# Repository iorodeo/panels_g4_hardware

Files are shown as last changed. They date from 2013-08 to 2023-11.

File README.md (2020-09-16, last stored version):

---
title: other Hardware
parent: Setup
grand_parent: Generation 4
nav_order: 4
---

# G4 Hardware

The original development of the G4 Hardware Panels. Currently, in the year 2020, the communication board and the programmer are still being used. The driver has been replaced with a specialized board. Also, there are different arena boards used.

The current version of the communication board (`comm`) and `programmer` are in `atmega328/four_panel/20mm_matrix/ver3`.

In addition, the directory `placeholder` contains a panel, which can be used as a drop in replacement for a panel with a 35mm×21mm opening to look through.

## Project structure

```
├── atmega328
│   ├── four_panel
│   └── one_panel
├── max6960
│   ├── four_panel
│   ├── one_panel
│   └── two_panel
├── stm32
│   ├── pcb_big_v0
│   └── pcb_big_v1
└── placeholder
```

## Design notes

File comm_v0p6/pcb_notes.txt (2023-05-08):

1. Fixed issue with schematic design rules check. Changed Schematic Setup ->
Electrical Rules -> Violation Severity -> Miscellaneous -> SPICE model issue to
ignore.

2. Problem with vias. Via hole (0.5mm) is larger than via diameter (0.3mm).
JLCPCB may have corrected this for you automatically. However, you could run
into an issue with other board houses. They will probably catch it, but it
might hang up the order.  JLCPCB specs say via diameter should be 0.1mm(0.15mm
preferred) larger than Via hole size.

3. Also, vias might be to small in general.  

4. Moved to 4-layer [sig+pwr, gnd, gnd, sig+pwr] stackup.

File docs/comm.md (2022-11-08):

---
title: Comm Board
parent: Acquisition
grand_parent: Generation 4
nav_order: 5
---

1. TOC
{:toc}

# Communication PCB

The communication PCB or "comm board" measures 40×40mm² and has a 15 pin connector on the bottom and a matching socket on the top edge. In addition, there are four 4×4 female sockets ([v0.3](#comm-v0p3)) or two 3×6 male pins ([v0.1](#comm-v0p1)) on the top side of the PCB. This board extracts data packets for the current panel from the SPI stream and sends them via I²C to the driver board. The connectors always need to be connected to either a adjacent comm board or an arena.

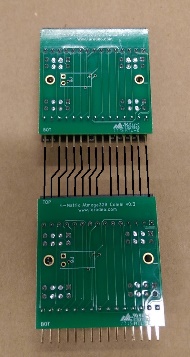
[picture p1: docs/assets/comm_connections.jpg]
Connections between panels


To identify packets for the current panel, each comm uses four of its connectors as "chip select" lines. This means, while the first chip select line is active, the comm board splits and forwards the received data to the driver board. Independently, the data is always forwarded to the next panel. In addition, the comm board drops the first chip select line from the input and makes the second input chip select line the first output chip select, the 3rd becomes second, and the fourth the 3rd output. This way, up to four stacked panel PCB can be addressed individually.

While the chip select line is active for the current panel, a micro controller unit (MCU) splits the incoming signal into smaller chunks. The driver boards are usually divided into quadrants, and the comm board forwards the matching data packages to the quadrants via I²C bus. The change of protocol has historic reasons. Most recent [comm boards v0.3](#comm-v0p3) use four connectors for the driver board, earlier versions had only two.

## Panel Comm PCB v0.3 {#comm-v0p3}

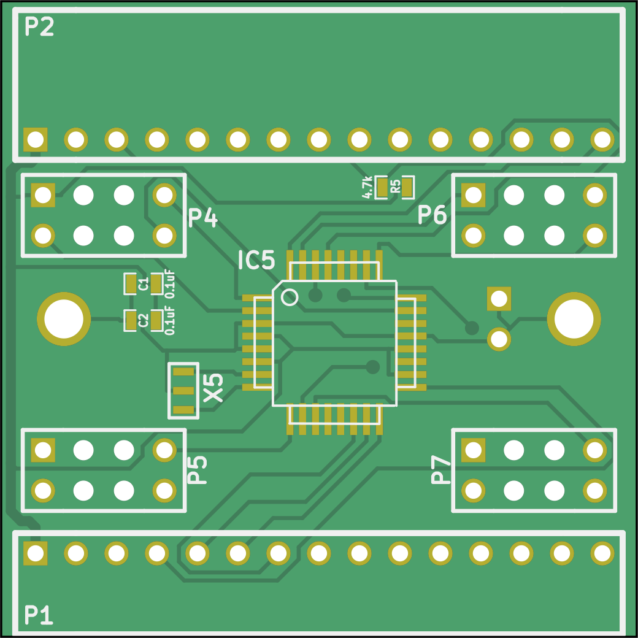
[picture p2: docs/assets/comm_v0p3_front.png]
A rendering of the communication board v0.3 front


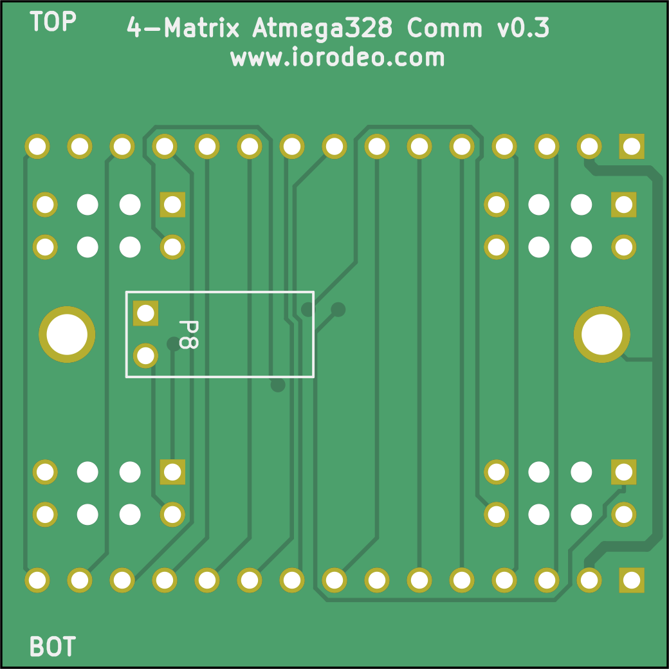
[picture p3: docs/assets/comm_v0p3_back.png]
A rendering of the communication board v0.3 back


The communication board is a 40×40mm² PCB with two layers, most recently available as version v0.3 available in `comm_v0p3` (see [schematic](assets/comm_v0p3_schematic.pdf)). The connectors are designed as through-hole, other components are SMD.

### Function

The comm board v0.3 receive signals (P1), send them on (P2). Based on the chip select line it identifies the signals relevant for the current panel. This processing is done with the help of a 20MHz ATmega328P-AUR (IC5). The relevant signals are passed to one of the four driver board quadrants (P4…P7).

### Design

The files are inside the `comm_v0p3` folder and find the production files inside the `comm_v0p3/production_v0/` directory.

The design files are shared under a creative commons license as [KiCad](https://kicad-pcb.org/) EDA source files. They were initially developed by [IORodeo](https://iorodeo.com). If you open the schematics in a current version of KiCad you might be asked to remap the symbols when you first open the files.

### Production

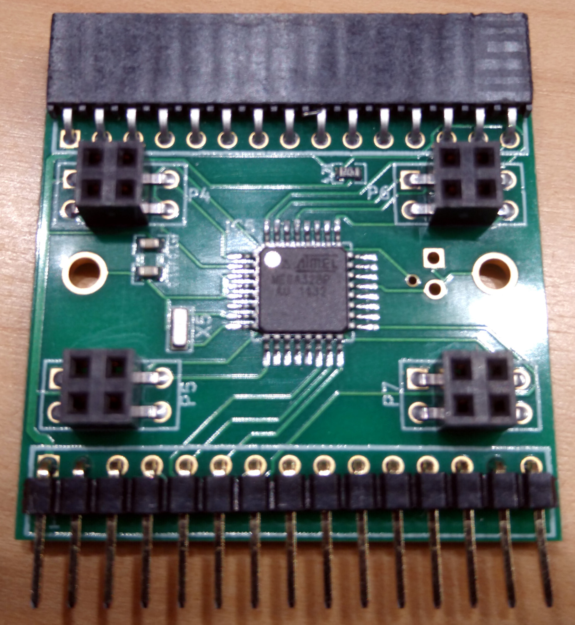
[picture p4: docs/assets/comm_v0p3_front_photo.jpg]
A picture of the assembled board v0.3


The Comm board v0.3 is a two layer PCB with 1oz copper that has no special requirements on the production process. We typically order them on the default FR-4. The board has through-hole components such as the connectors, but the majority of components are SMD with the smallest package of 0603 (imperial) or 1608 (metric).

For an order volume of 150 pieces we would expect prices around $16 for the assembled board. This might be around $1.50 for the board, $8 for the components, $6 for the assembly, and $.50 for shipping. Recently we have had good experiences with [Bittele](https://www.7pcb.com/). If you decide to order at Bittele, you can provide quotation Q70762A1 and order number 39493C2 as references for successful builds.

## Panel Window PCB {#window}

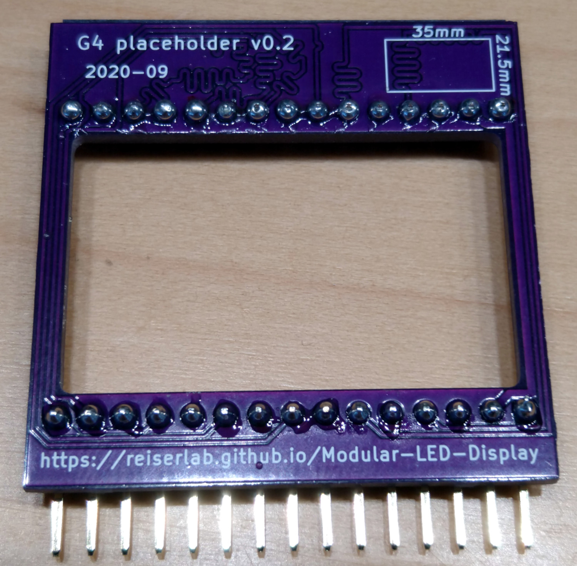
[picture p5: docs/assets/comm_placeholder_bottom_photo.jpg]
The assembled window PCB (as "placeholder v0.2")


This PCB acts as a drop-in replacement for panels within a column. It has a cut out of 35×21mm² which you can use to point a camera or other device through that column. In most cases this is not needed, yet it is the most simple and cheap PCB you can get produced from the G4 system. So if you haven't had any experience with the process of ordering PCBs, you might want to start here. Before version v0.3 this was called "placeholder".

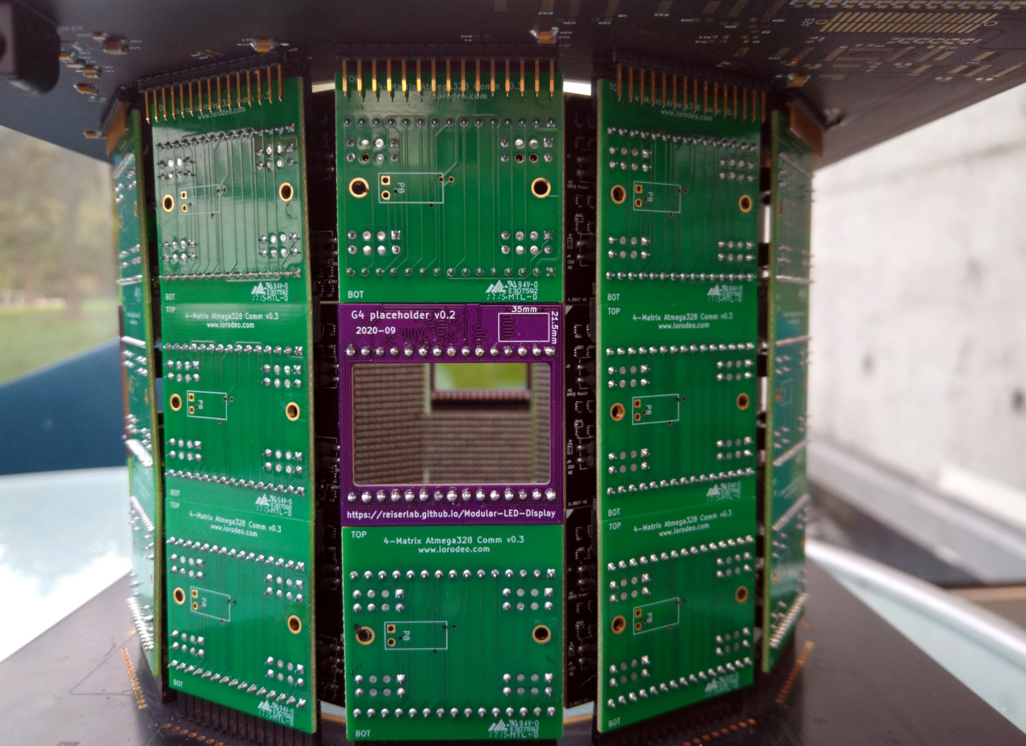
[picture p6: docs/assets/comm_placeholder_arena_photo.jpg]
Window PCB placed in a full 12-12 arena v1, allowing to see through


If you want to skip a panel within a column, you will need to connect the chip select lines accordingly. The image on the right shows which input and output connectors your want to connect. Note, that the signal is travelling from the bottom to the top. This has often been done with wires.

Alternatively you can use the window PCB to achieve the same. The PCB has the same outer dimensions and same connectors as the Comm PCB and provides the wiring described above between input and output.

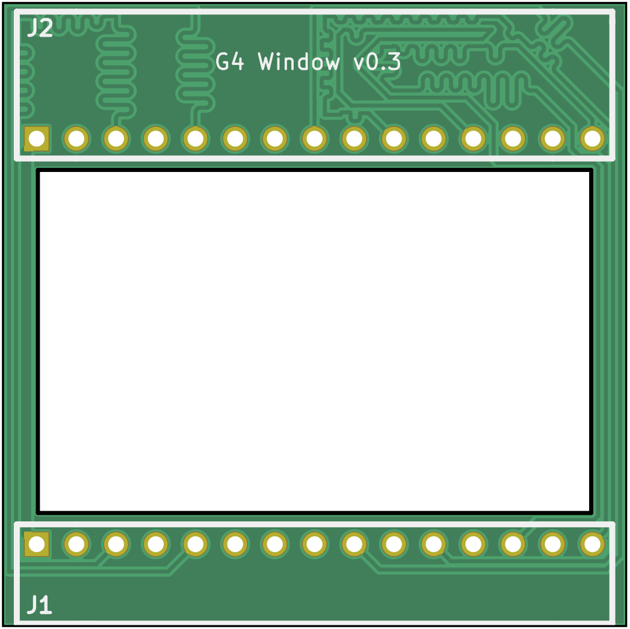
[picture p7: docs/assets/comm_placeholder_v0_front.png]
A rendering of the "window" v0.3 (front)


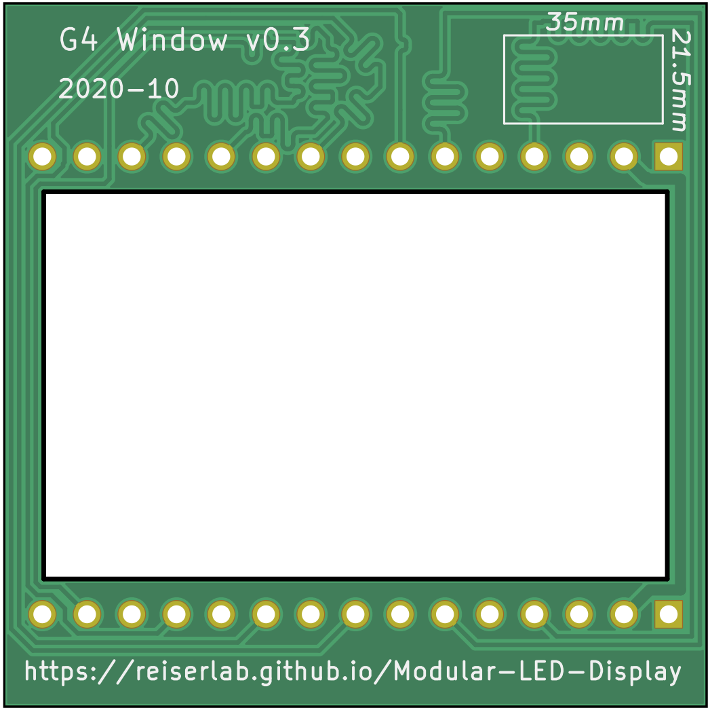
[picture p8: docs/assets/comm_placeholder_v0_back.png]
A rendering of the "window" v0.3


The KiCad design files for this simple 2-layer PCB are in the folder `comm_placeholder_v0`. The files ready for production are inside the `comm_placeholder_v0/production_v0` folder. Most recently `comm_placeholder_v0p3.zip` uses length matched traces. All you need to order this design is the zip file, which contains the relevant files from the directory, and most manufacturers will accept. So far we have ordered this exact design from [OSHPark](https://oshpark.com/) with a quick turn-around time of around 5 days and a total cost of $10 per board, including components. With enough lead time, higher quantities, and other manufacturers the price should be around $1 per unit. For example, in October 2020 an order of 30 window PCB at [JLCPCB](https://jlcpcb.com/) cost less than $20 including shipping and was delivered within 14 days.

The window might be a good start to familiarize yourself with file types, the organization of our repositories, and the whole production process, if you have never done that before. Otherwise please apologize the boring details in the text above.

# Connections

The bottom pins have the following meanings, seen from the direction of the driver:

| No | Name | Description  |
| --:|:---|:---|
|  1 | `5VCC` | (5V Power) |
|  2 | `GND` | (Ground) |
|  3 | `RESET_MAIN` | (Reset all panels) |
|  4 | `SCK` | (Serial Clock) |
|  5 | `COPI` | (Controller Out, Peripheral In) |
|  6 | `CIPO` | (Controller In, Peripheral Out) |
|  7 | `CS1` | (Chip Select 1) |
|  8 | `CS2` | (Chip Select 2) |
|  9 | `CS3` | (Chip Select 3) |
| 10 | `CS4` | (Chip Select 4) |
| 11 | `CS5` | (Chip Select 5) |
| 12 | `CS6` | (Chip Select 6) |
| 13 | `CS7` | (Chip Select 7) |
| 14 | `NC` | (Not Connected) |
| 15 | `EXT_INTO` |  |

Here, `SCK`, `COPI`, `CIPO`, and `CSx` are used for the SPI communication. `RESET_MAIN` sends a reset signal to all MCUs.

# Historic designs

These designs are kept for historic reasons and to debug existing systems. If you have one of them, you probably know what to do and just need the files. If you are building a new system, don't use them.

## Panel Comm PCB v0.2 {#comm-v0p2}

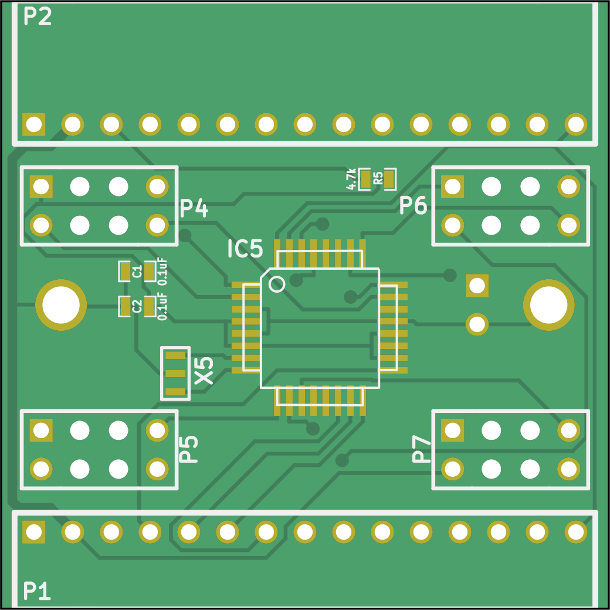
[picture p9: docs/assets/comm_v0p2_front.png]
Rendering of the communication board v0.2 (front)


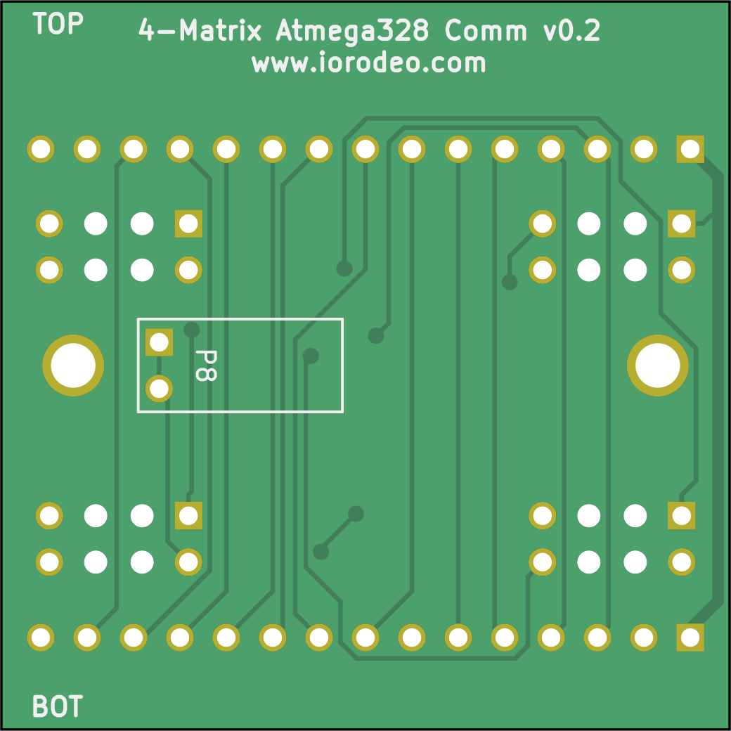
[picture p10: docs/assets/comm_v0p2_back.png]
Rendering of the communication board v0.2 (back)


In theory, the v0.2 should have a 2×3 pin connector that was used for a brief time in certain drivers. The actual comm board with the 2×3 connector seems to be lost, so at this time we are not sure what version 0.2 is. If you wanna try and have a look at the [schematic](assets/comm_v0p2_schematic.pdf), feel free to use the project files in `comm_v0p2`.

Everything else regarding design and production is very similar to the [Comm board v0.3](#comm-v0p3). There is no reason to build a comm board v0.2, except maybe replacing a broken one. Even then you might consider an upgrade of your hardware instead, especially with the unknown background.

The original documentation for v0.2 contained hints that the communication was changed from I²C to SPI and that the board-to-board headers were improved.

## Panel Comm PCB v0.1
{:.clear #comm-v0p1}

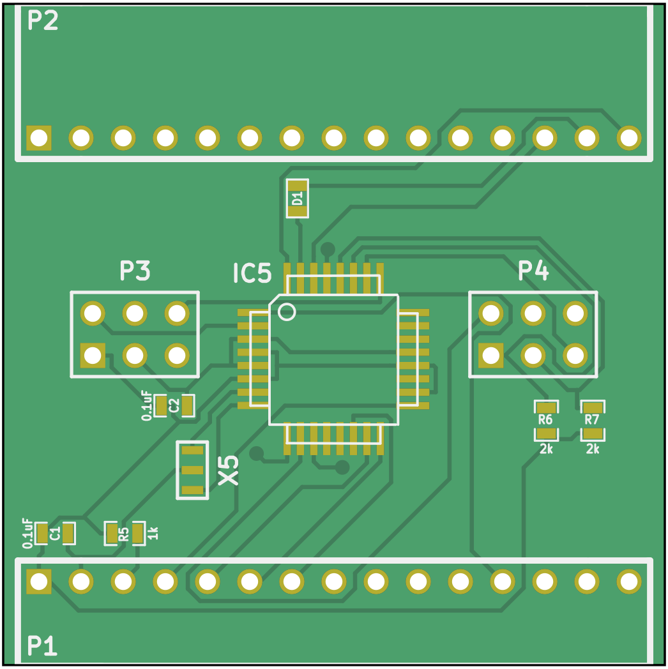
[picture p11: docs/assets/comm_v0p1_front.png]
Rendering of the communication board v0.1 (front)


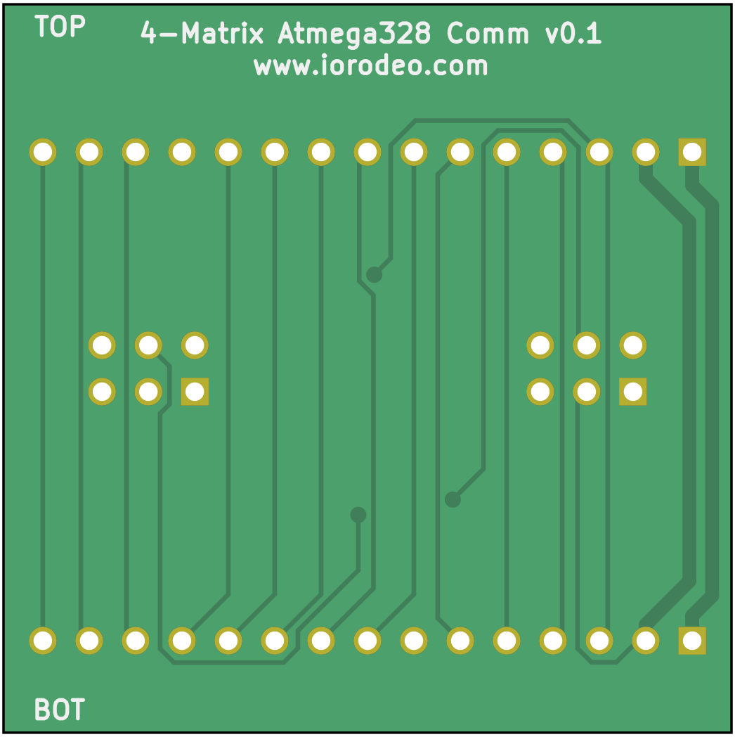
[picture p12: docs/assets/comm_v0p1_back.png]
Rendering of the communication board v0.1


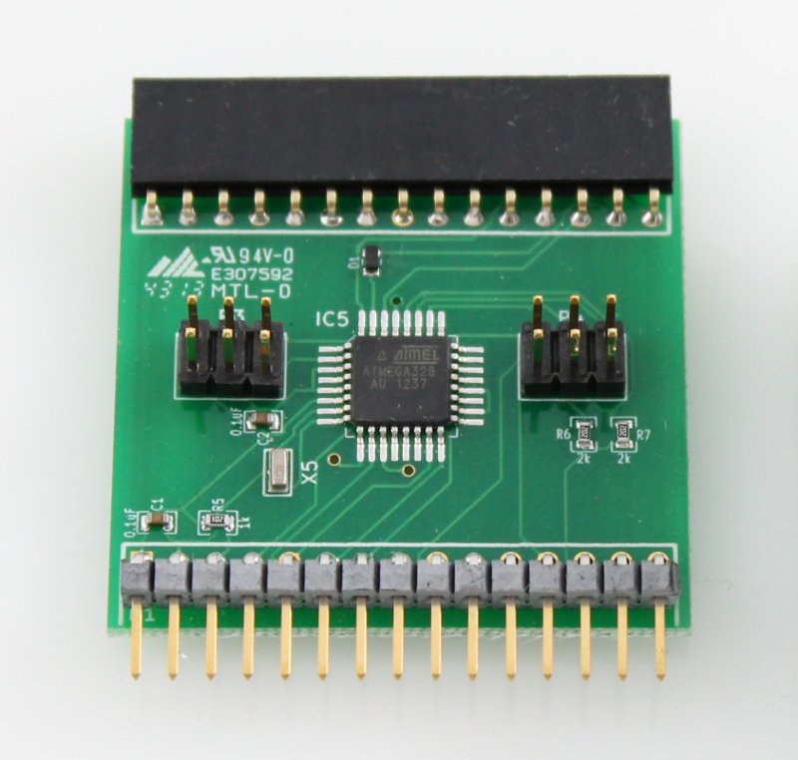
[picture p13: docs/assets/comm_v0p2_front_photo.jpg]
A picture of the assembled comm board v0.1 (front)


`comm_v0p1` contains an earlier comm board project (see [schematic](assets/comm_v0p1_schematic.pdf)). This uses a different communication protocol and is not compatible with drivers-v0.2 and up. The files are there, should you need to repair your existing system with [driver-v0.1]({{site.baseurl}}/Generation%204/Panel/docs/driver.html#driver-v0p1).

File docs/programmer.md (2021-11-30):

---
title: Programmer
parent: Acquisition
grand_parent: Generation 4
nav_order: 8
---

1. TOC
{:toc}

# Programmer

The programmer is built from 3 PCB: An Arduino shield, the comm programmer, and the driver programmer. The three boards are designed to be assembled by hand: These simple 2-layer boards use very few through-hole components and only one of each board is needed for the setup of an arena.

The use of the programmer is explained in more detail in the [Assembly → Firmware section]({{site.baseurl}}/Generation%204/Firmware/docs/), but the general principle is as follows: The Arduino shield needs to be mounted on an Arduino. The same shield can be used for programming the communication boards and the driver boards. Connect the corresponding programmer board via a ribbon cable to the Arduino shield, and the board you want to program to the programmer board.

## Arduino shield {#arduino-shield}

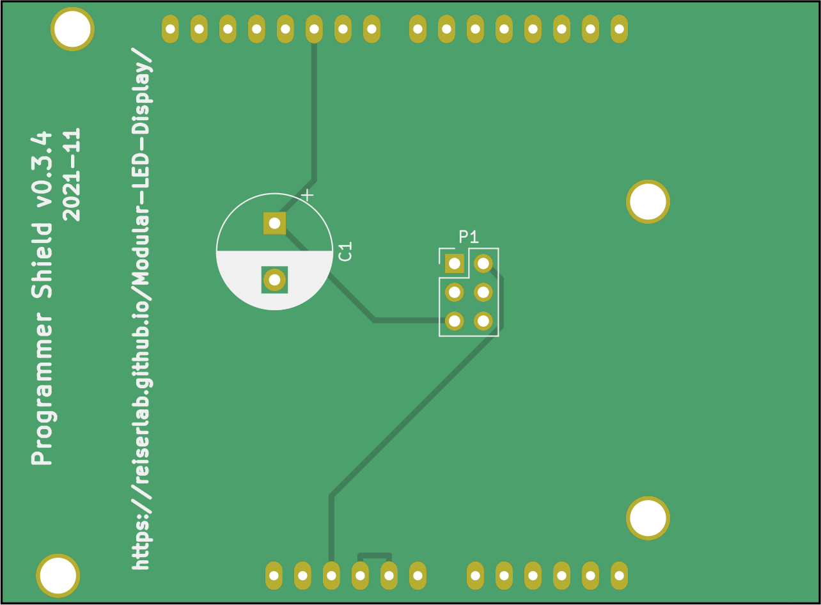
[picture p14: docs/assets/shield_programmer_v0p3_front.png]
The arduino shield for the programmer version 0.3.4 (front)


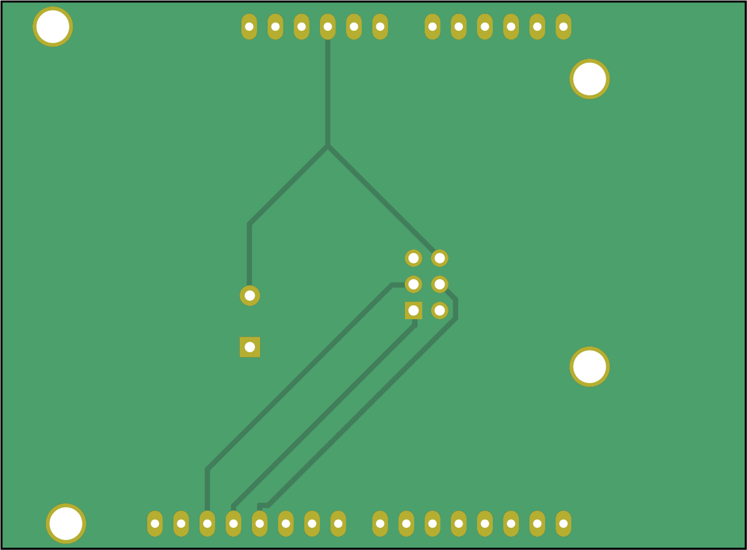
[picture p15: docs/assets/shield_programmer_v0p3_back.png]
The arduino shield for the programmer version 0.3.4


The Arduino programming shield measures 72.39×53.34mm². The gerber files and a drill file of the most recent version v0.3.4 (see [schematics](assets/shield_programmer_v0p3_schematic.pdf)) are archived in `shield_programmer_v0p3/production_v0/shield_programmer_v0p3r4.zip` but have never been produced. They should fix the issue mentioned in the _Quick Fix_ below. The most recent version that was produced is v0.3.1 in the same directory.

### Function of the Arduino shield

The basic functionality of the Arduino shield is to convert the signals from the Arduino connectors on the side the ribbon connector (P1).

### Quick Fix
{:.clear}

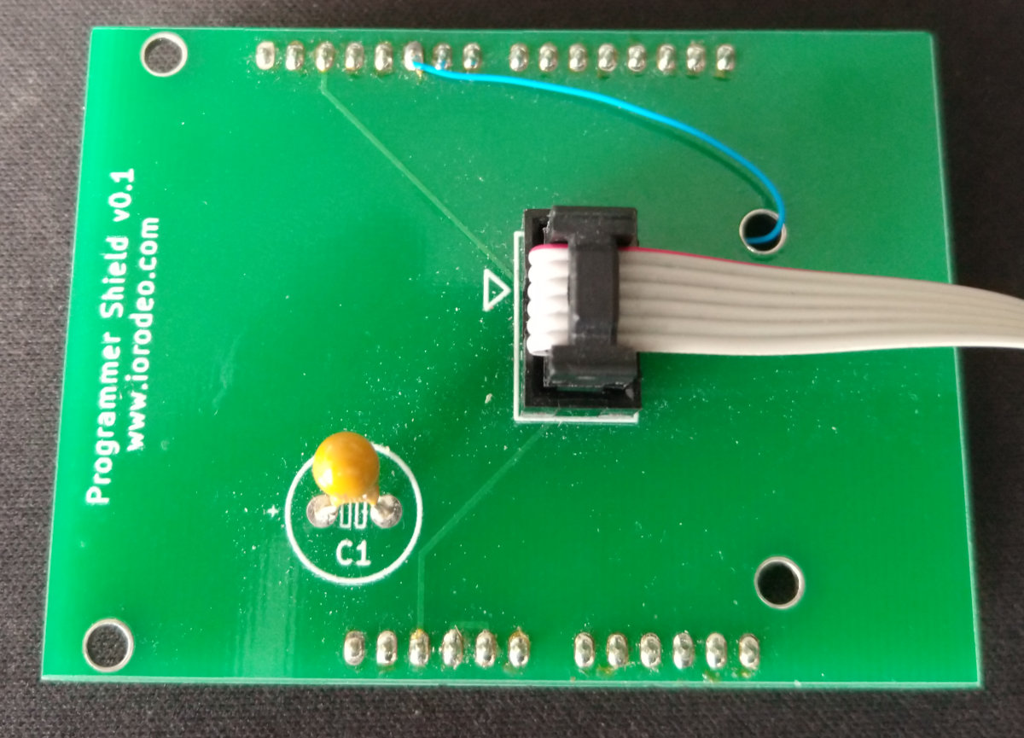
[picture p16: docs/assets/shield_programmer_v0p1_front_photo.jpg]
The front of the Arduino shield board with the quick fix


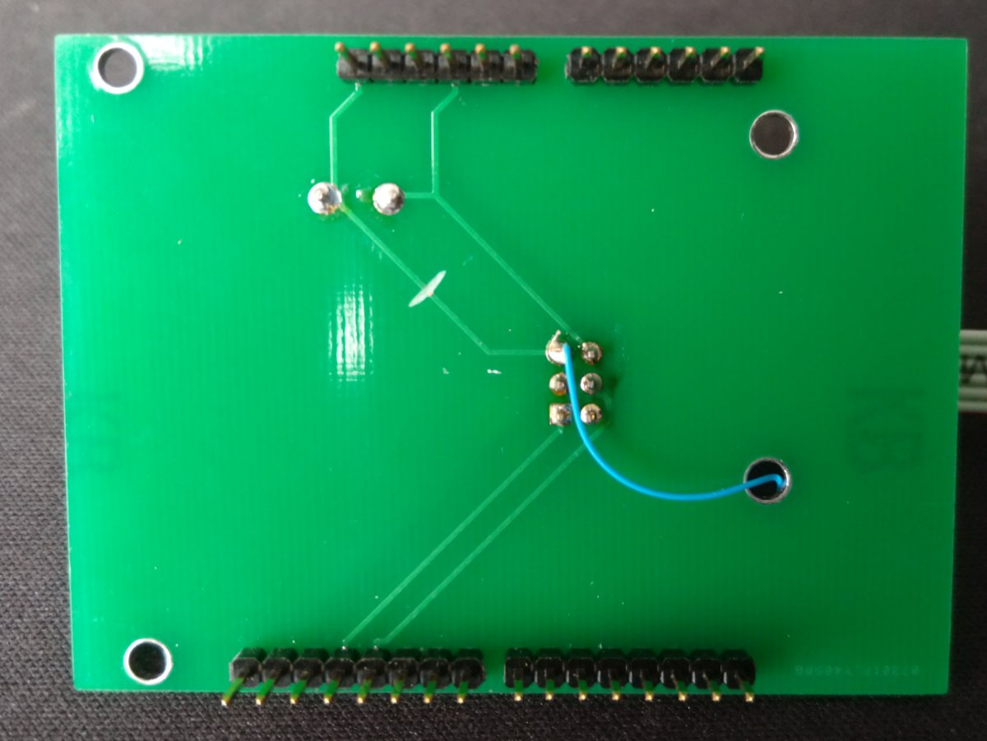
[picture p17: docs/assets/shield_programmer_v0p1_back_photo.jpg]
The Arduino shield board with the quick fix The back of the Arduino shield board with the quick fix


Apparently there is an error in the arduino shields prior to version v0.3.4 of the programmer. If you happen to have one of those programmers, please cut the trace on the bottom as shown in the image on the right and add a new connection as demonstrated in the two images. Alternatively you can try to produce v0.3.4 and [let us know]({{site.baseurl}}/Contact) how it worked.

## Driver board shield {#driver-shield}

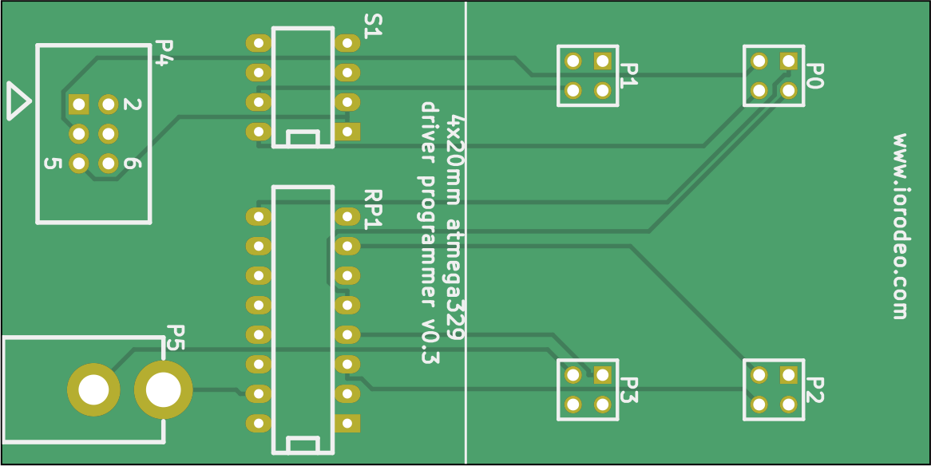
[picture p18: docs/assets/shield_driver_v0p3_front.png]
The driver shield for programming the four MCUs (front)


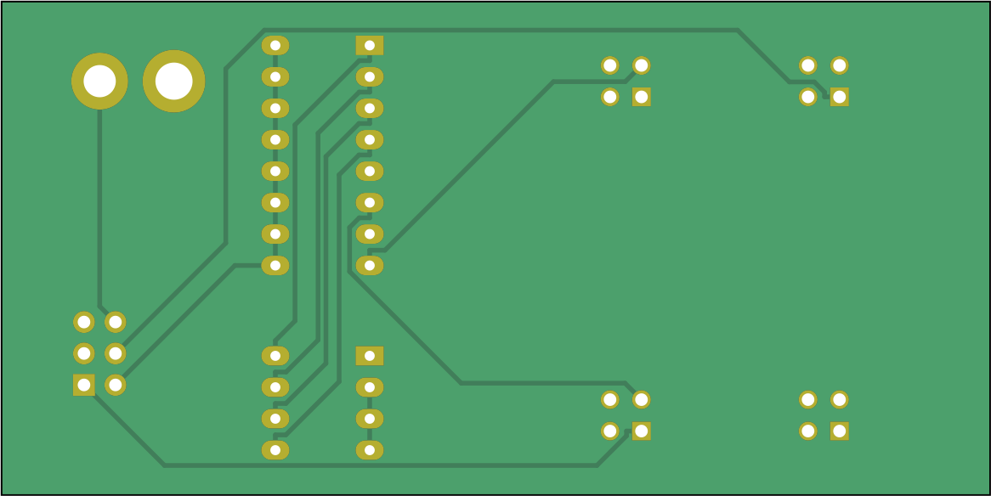
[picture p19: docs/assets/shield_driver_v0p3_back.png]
The driver shield for programming the four MCUs


The driver programmer has double the size of a panel board, it is 40×80mm².

The most recent version of the production files is version v0.3 in `shield_driver_v0p3/production_v0/shield_driver_v0p3.zip` (see [schematics](assets/shield_driver_v0p3_schematic.pdf). Once again this directory contains a zip file ready to be used with a manufacturer. The production files contain gerber files, a drill file, and a BOM.

### Function of the driver board shield

The shield adapts the signal from the ribbon connector (P4) to the four driver board connectors (P0…P3), while also powering the driver board during programming (P5). The switch (S1) allows to select which driver MCU will be programmed (usually all 4 are on).

## Comm board shield {#comm-shield}

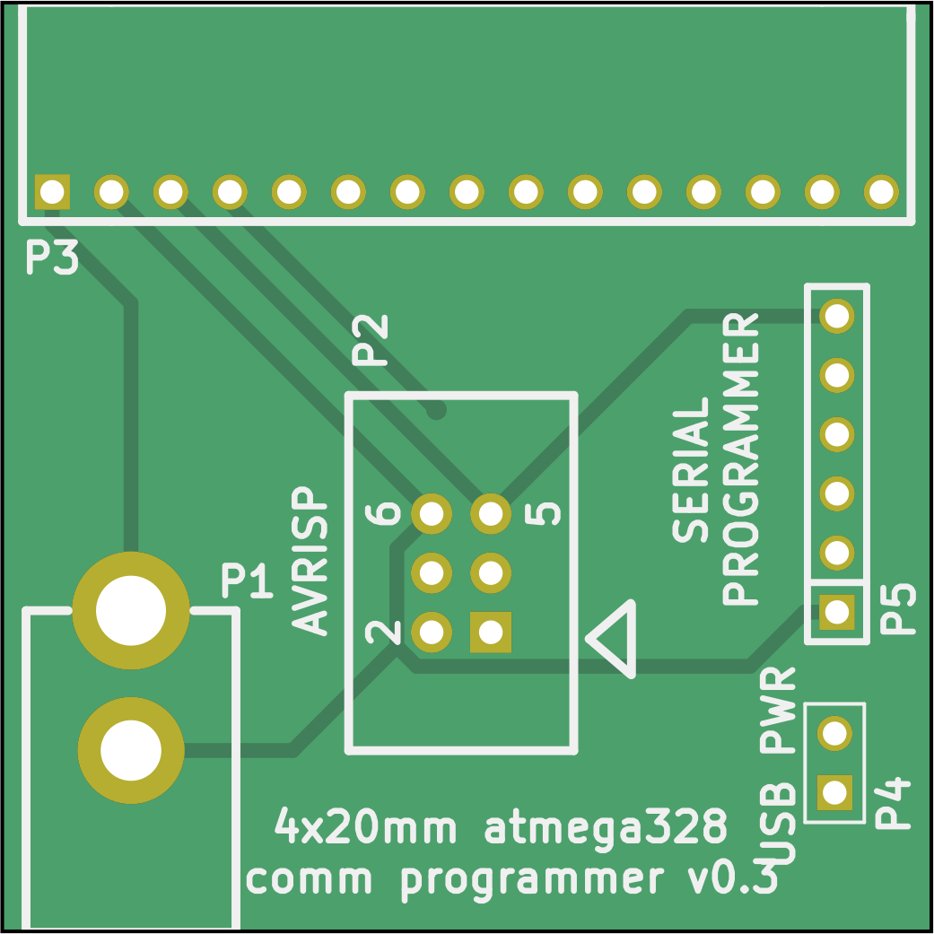
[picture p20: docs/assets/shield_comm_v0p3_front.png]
The shield for programming comm boards (front)


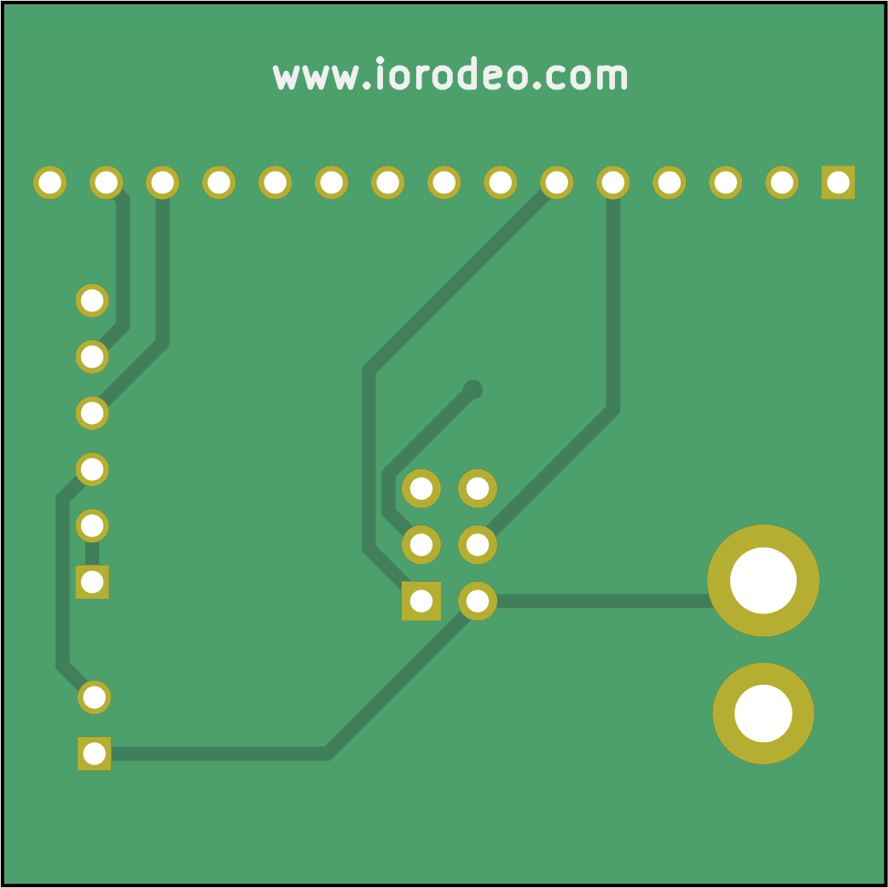
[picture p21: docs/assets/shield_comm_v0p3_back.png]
The shield for programming comm board


With 40×40mm² the PCB for the communication board programmer has the same dimensions as a communication board or a driver board. The most recent KiCad design files are at `shield_comm_v0p3` (also see [schematics](assets/shield_comm_v0p3_schematic.pdf)).

Production files for the communication board programmer are available in version v0.3, also as a zip file at `shield_comm_v0p3/production_v0/shield_comm_v0p3.zip` ready for submission. The production files contain the gerber files, drill file, and a "Bill of Materials" (BOM) as an xlsx file (Office Open XML format used by Microsoft Office).

### Function of the comm board shield

The shield adapt the signal from the Arduino (P2) to the communication board connector (P3), while also powering the communication board during programming (P1).

# Design

These boards were initially developed by [IORodeo](https://iorodeo.com) in 2013 and shared under a creative commons license.

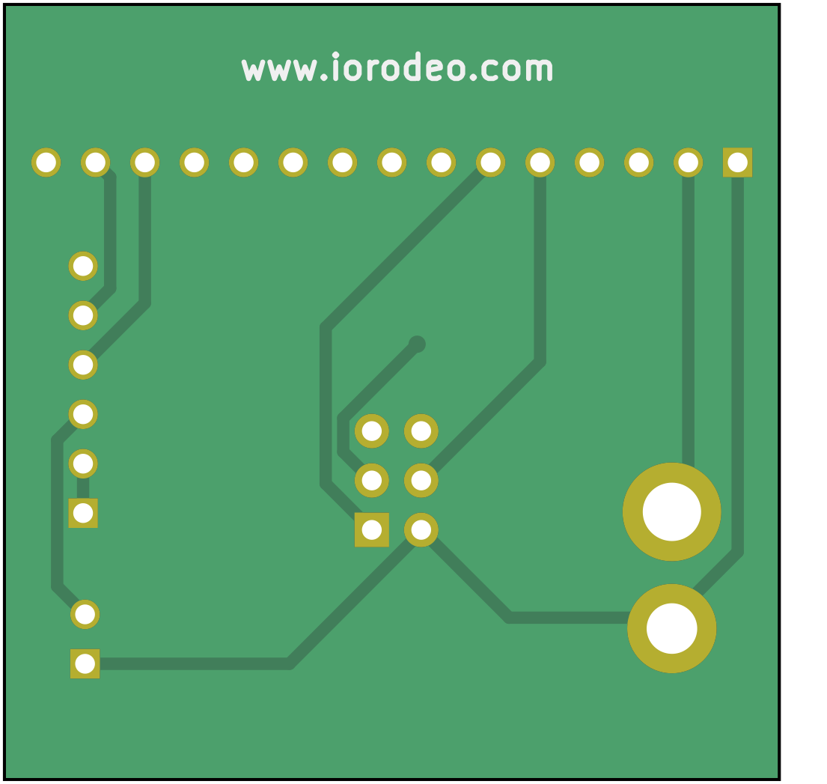
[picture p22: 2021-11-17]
docs/assets/shield_comm_v0p1_back.png

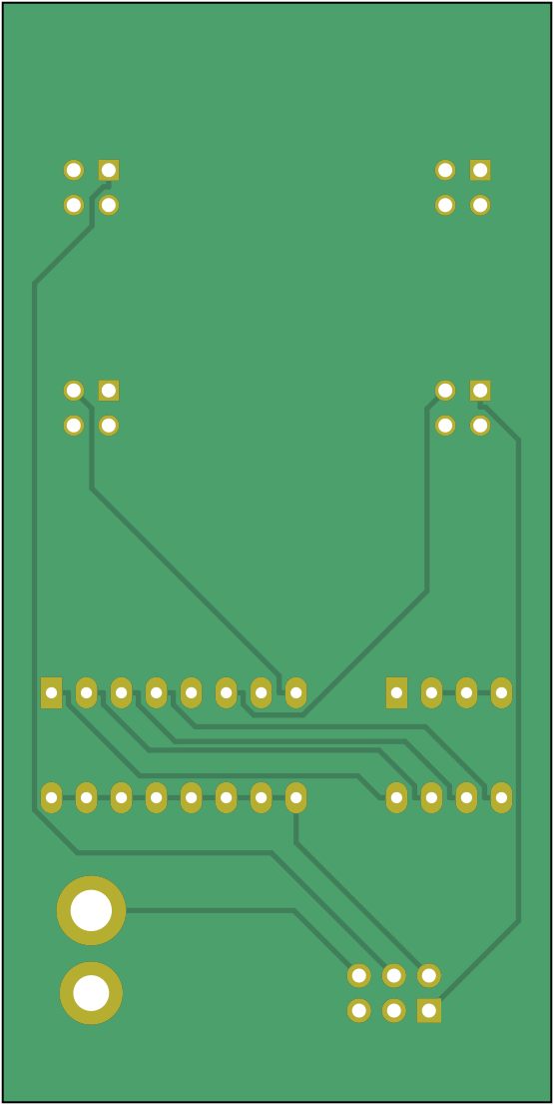
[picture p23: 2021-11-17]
docs/assets/shield_driver_v0p2_back.png

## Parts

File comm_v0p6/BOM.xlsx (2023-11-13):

Comment | Designator | Footprint | LCSC Part # | Digikey Part # | Qty
16V 1uF Multilayer Ceramic Capacitor | C1,C2 | 0402 | C5137499 | 1276-1067-1-ND | 2
10uF 50V Multilayer Ceramic Capacitor | C3 | 0805 | C2932476 | CL21A106KBYQNNE | 1
Conn Header R/A 15pos 2.54mm | J1 | Push-Pull,P=2.54mm | C247916 | 2057-PH1RB-15-UA-ND | 1
Conn Receptacle R/A 15pos 2.54mm | J2 | Push-Pull,P=2.54mm | C2897397 | 612-SSQ-115-02-G-S-RA-ND | 1
Conn Receptacle 2X2 2.54mm | J4,J5,J6,J7 | Plugin,P=2.54mm | C718234 | A125237-ND | 4
4.7k Chip Resistor | R5 | 0603 | C105428 | 311-4.7KGRCT-ND | 1
ATmega328P | U1 | VFQFN-32-EP(5x5) | Global Parts | ATMEGA328P-MURTR-ND | 1
20MHz ±0.5% 15pF 40Ω Ceramic Resonator | Y1 | SMD3213-3P | C882604 | 490-17953-1-ND | 1

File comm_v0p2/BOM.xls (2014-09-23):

Modified components: P1, P4-P7, R5
Item # | Qty | Reference | Descritpion | P/N | Vendor
1 | 2 | C1, C2 | 0.1uF ceramic capacitor, SM0603 | 1276-1258-6-ND | Digikey
2 | 1 | IC5 | Atmel Atmega328, 20MHz | ATMEGA328P-AURCT-ND | Digikey
3 | 1 | P1 | 15 position right angle male header, 0.1” pitch | S1111EC-15-ND | Digikey
4 | 1 | P2 | 15 position right angle female header, 0.1” pitch | SAM1195-15-ND | Digikey
5 | 2 | P4-P7 | 2x2 female pass through header, 0.1” pitch | 3M9549-ND | Digikey
6 | 1 | R5 | 4.7k Ohm resistor,SM0603 | 311-4.7KGRCT-ND | Digikey
7 | 1 | X5 | 20MHz ceramic resonator | 490-1199-6-ND | Digikey

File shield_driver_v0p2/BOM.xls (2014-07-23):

Item # | Qty | Reference | Description | PN | Vendor
1 | 4 | P0-P3 | 2x2 male header, 0.1” pitch | 952-2119-ND | Digikey
2 | 1 | P4 | 3x2 male header, shourded, 0.1” pitch | 854 | Pololu
3 | 1 | P5 | DC Jack, 2.1mm, 2 pin | 137673 | Jameco
4 | 1 | RP1 | Resistor array, 8 resistor, 10k | 4116R-1-103LF-ND | Digikey
5 | 1 | S1 | Dip switch, 4 pos | 450-1358-ND | Digikey

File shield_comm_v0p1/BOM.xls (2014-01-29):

Item # | Qty | Reference | Descritpion | P/N | Vendor
1 | 1 | P1 | 2.1mm DC Jack 2-pin | 137673 | Jameco
2 | 1 | P2 | 3x2 shrouded header | 854 | Pololu
3 | 1 | P3 | 15 position right angle female header, 0.1” pitch | S5490-ND, SAM1195-15-ND | Digikey
4 | 1 | P4 | 2x1 male header, break away | A26513-40-ND | Digikey
5 | 1 | P5 | 6x1 male header, break away | A26513-40-ND | Digikey
Extra
1 | 1 | P2 | Mating IDC socket for 3x2 shrouded header | 855 | Pololu

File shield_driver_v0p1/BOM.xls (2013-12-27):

Item # | Qty | Reference | Descritpion | P/N | Vendor
1 | 1 | P1 | 2.1mm DC Jack 2-pin | 137673 | Jameco
2 | 2 | P2, P3 | 3x2 pin array 0.1” spacing | 952-2121-ND | Digikey
3 | 2 | P4, P6 | 3x2 shrouded header | 854 | Pololu
4 | 1 | P5 | 2x1 male header, break away | A26513-40-ND | Digikey
Extra
1 | 1 | P2 | Mating IDC socket for 3x2 shrouded header | 855 | Pololu

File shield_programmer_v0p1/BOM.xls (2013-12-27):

Item # | Qty | Reference | Descritpion | P/N | Vendor
1 | 1 | Matrix1-Matrix4 | Mill-Max strip headers 0.1”, fine pin – break away 64 pos | ED3864-ND | Digikey
2 | 64 | Matrix5-Matrix8 | Elpakco PIN recepticals | 4007-2-01-32-12 | Elpakco (via Straight Road Electronics)
3 | 5 | P1-P5 | 3x2 shrouded header | 854 | Pololu
4 | 4 | P6, P8, P10, P12 | 2x1 male header, break away | A26513-40-ND | Digikey
5 |  | P7, P9, P11, P13 | 6x1 male header, break away | A26513-40-ND | Digikey
Extra
1 | 1 | P2 | Mating IDC socket for 3x2 shrouded header | 855 | Pololu

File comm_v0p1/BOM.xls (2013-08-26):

Item # | Qty | Reference | Descritpion | P/N | Vendor
1 | 2 | C1, C2 | 0.1uF ceramic capacitor, SM0603 | 1276-1258-6-ND | Digikey
2 | 1 | D1 | Diode standard, SM0603 | CD0603-S0180CT-ND | Digikey
3 | 1 | IC5 | Atmel Atmega328, 20MHz | ATMEGA328-AURDKR-ND | Digikey
4 | 1 | P1 | 15 position right angle male header, 0.1” pitch | A32702-40-ND | Digikey
5 | 1 | P2 | 15 position right angle female header, 0.1” pitch | S5490-ND | Digikey
6 | 2 | P3, P4 | 3x2 male header, 0.1” pitch | 609-3210-ND | Digikey
7 | 1 | R5 | 1k Ohm resistor,SM0603 | P1.0KGCT-ND | Digikey
8 | 2 | R6, R7 | 2k Ohm resistor, SM0603 | P2.0KGCT-ND | Digikey
9 | 1 | X5 | 20MHz ceramic resonator | 490-1199-6-ND | Digikey

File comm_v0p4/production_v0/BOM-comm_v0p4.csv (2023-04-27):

Comment | Designator | Footprint | JLCPCB Part #
4.7K | R5 | R_0603_1608Metric | C105428
100nF | C3,C1,C2 | C_0603_1608Metric | C66501
CSTNE20M0V530000R0 | Y1 | Resonator_SMD_Murata_CSTxExxV-3Pin_3.0x1.1mm | C882604
ATmega328PB-MUR | U1 | QFN-32-1EP_5x5mm_P0.5mm_EP3.1x3.1mm | C2651953

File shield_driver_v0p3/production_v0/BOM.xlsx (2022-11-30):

Item # | Qty | Reference | Description | PN | Vendor | unit price | price
1 | 4 | P0-P3 | 4 Position Receptacle Connector 0.100" (2.54mm) Through Hole Gold | A26452-ND | Digikey | 1.71 | 6.84
2 | 1 | P4 | 3x2 male header, shourded, 0.1” pitch | 854 | Pololu | 0.97 | 0.97
3 | 1 | P5 | DC Jack, 2.1mm, 2 pin | 137673 | Jameco | 0.45 | 0.45
4 | 1 | RP1 | Resistor array, 8 resistor, 10k | 4116R-1-103LF-ND | Digikey | 0.76 | 0.76
5 | 1 | S1 | Dip switch, 4 pos | 450-1358-ND | Digikey | 0.74 | 0.74
Extra
1 | 2 | P2 | Mating IDC socket for 3x2 shrouded header | 855 | Pololu | 0.97 | 1.94
 |  |  |  |  |  |  | 11.7

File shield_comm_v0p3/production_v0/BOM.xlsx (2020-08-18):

Item # | Qty | Reference | Descritpion | P/N | Vendor | Unit price | price
1 | 1 | P1 | 2.1mm DC Jack 2-pin | 137673 | Jameco | 0.45 | 0.45
2 | 1 | P2 | 3x2 shrouded header | 854 | Pololu | 0.97 | 0.97
3 | 1 | P3 | 15 position right angle female header, 0.1” pitch | S5490-ND, SAM1195-15-ND | Digikey | 2.26 | 2.26
4 | 1 | P4 | 2x1 male header, break away | A26513-40-ND | Digikey | 2.93 | 2.93
5 | 1 | P5 | 6x1 male header, break away | A26513-40-ND | Digikey | 0 | 0
 |  |  |  |  |  |  | 0
 |  |  |  |  |  |  | 0
Extra |  |  |  |  |  |  | 0
1 | 2 | P2 | Mating IDC socket for 3x2 shrouded header | 855 | Pololu | 0.97 | 1.94
 |  |  |  |  |  |  | 8.55

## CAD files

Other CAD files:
panel-tester_arduino-uno/pane-tester_arduino-uno_edge-cuts.FCStd
panel-tester_arduino-uno/pane-tester_arduino-uno_edge-cuts.dxf

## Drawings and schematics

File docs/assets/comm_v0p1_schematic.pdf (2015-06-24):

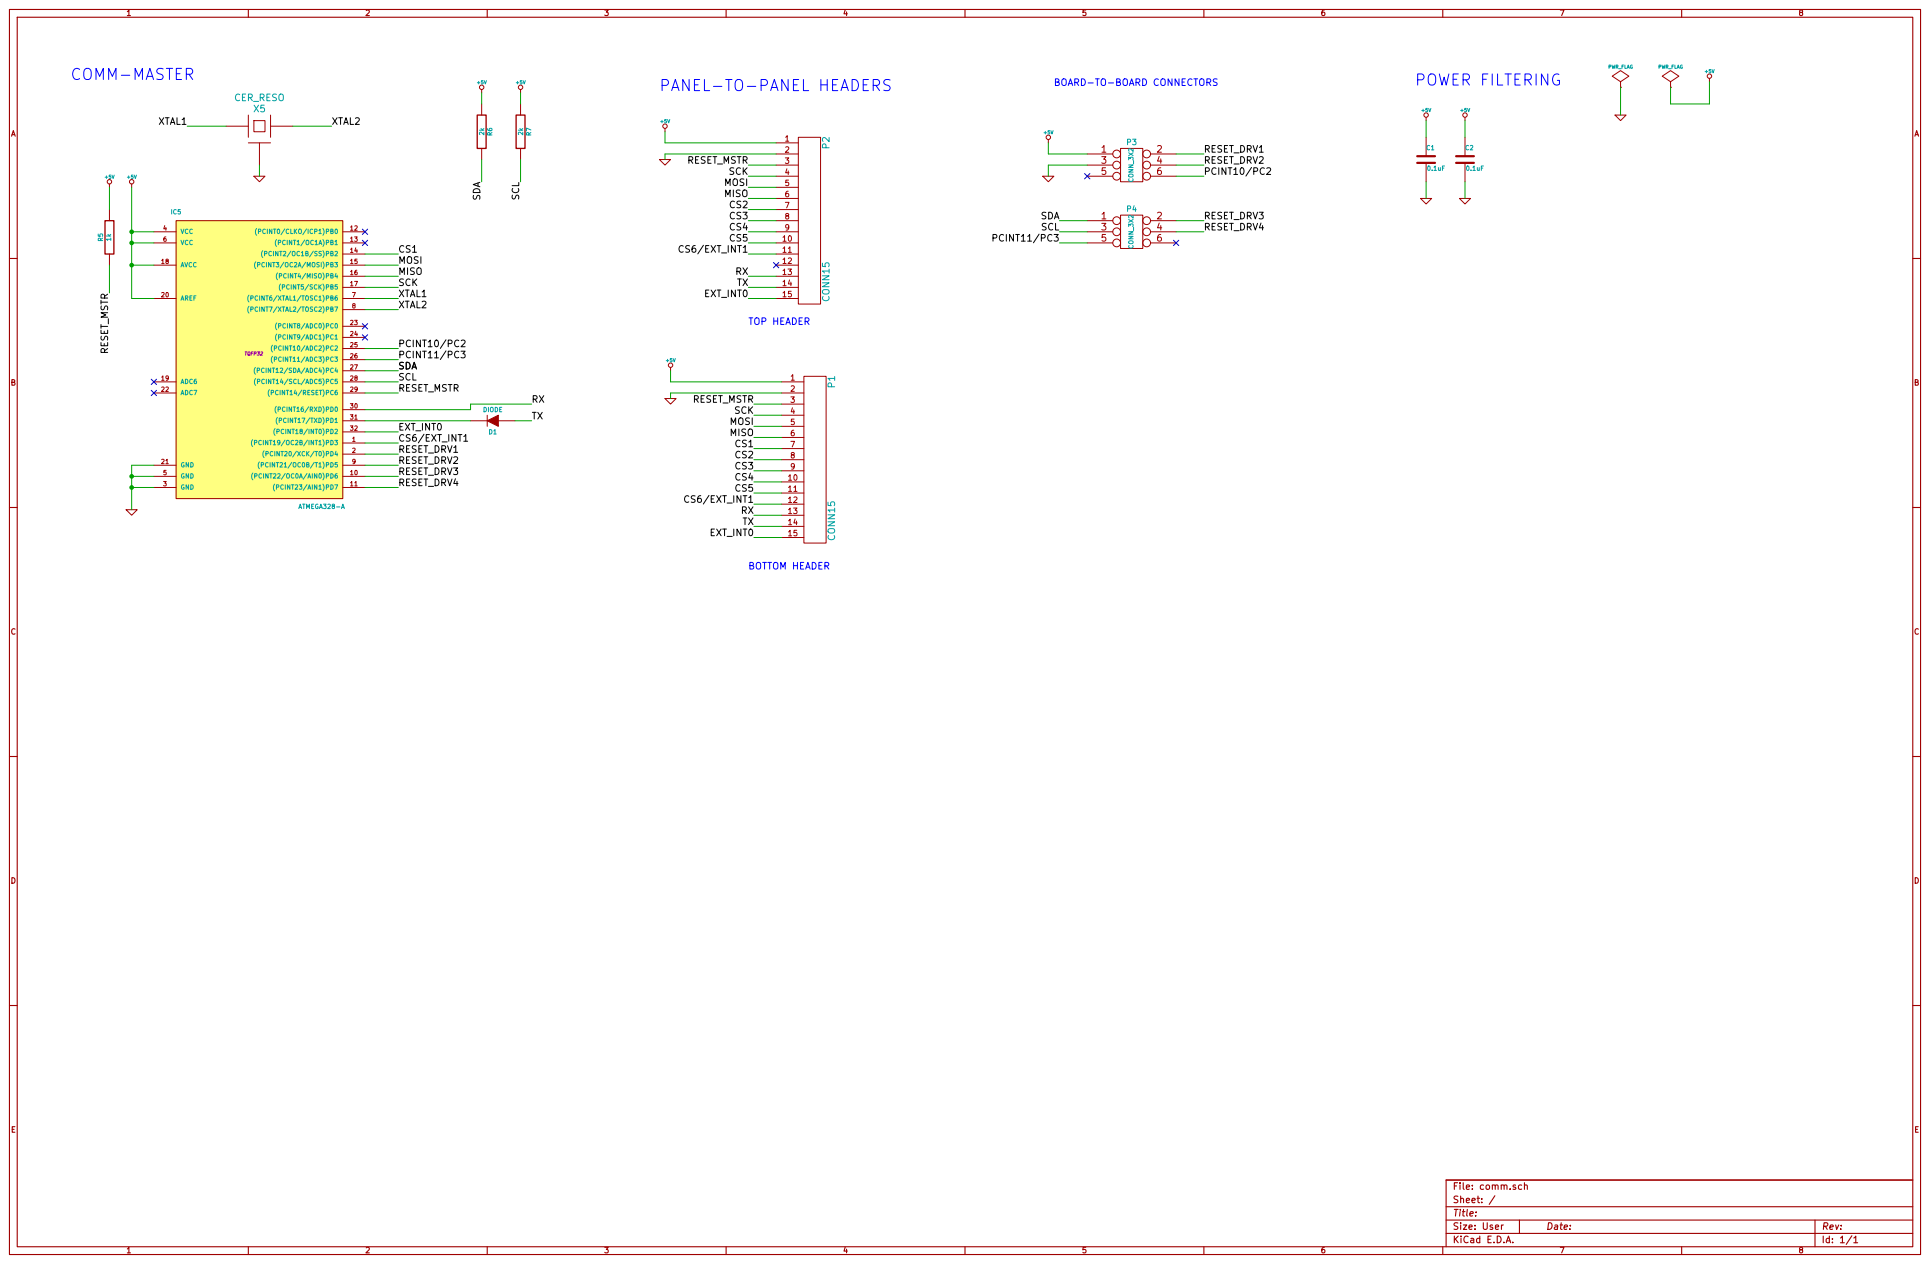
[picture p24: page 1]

BOARD-TO-BOARD CONNECTORS

Id: 1/1 Title: File: comm.sch Sheet: /

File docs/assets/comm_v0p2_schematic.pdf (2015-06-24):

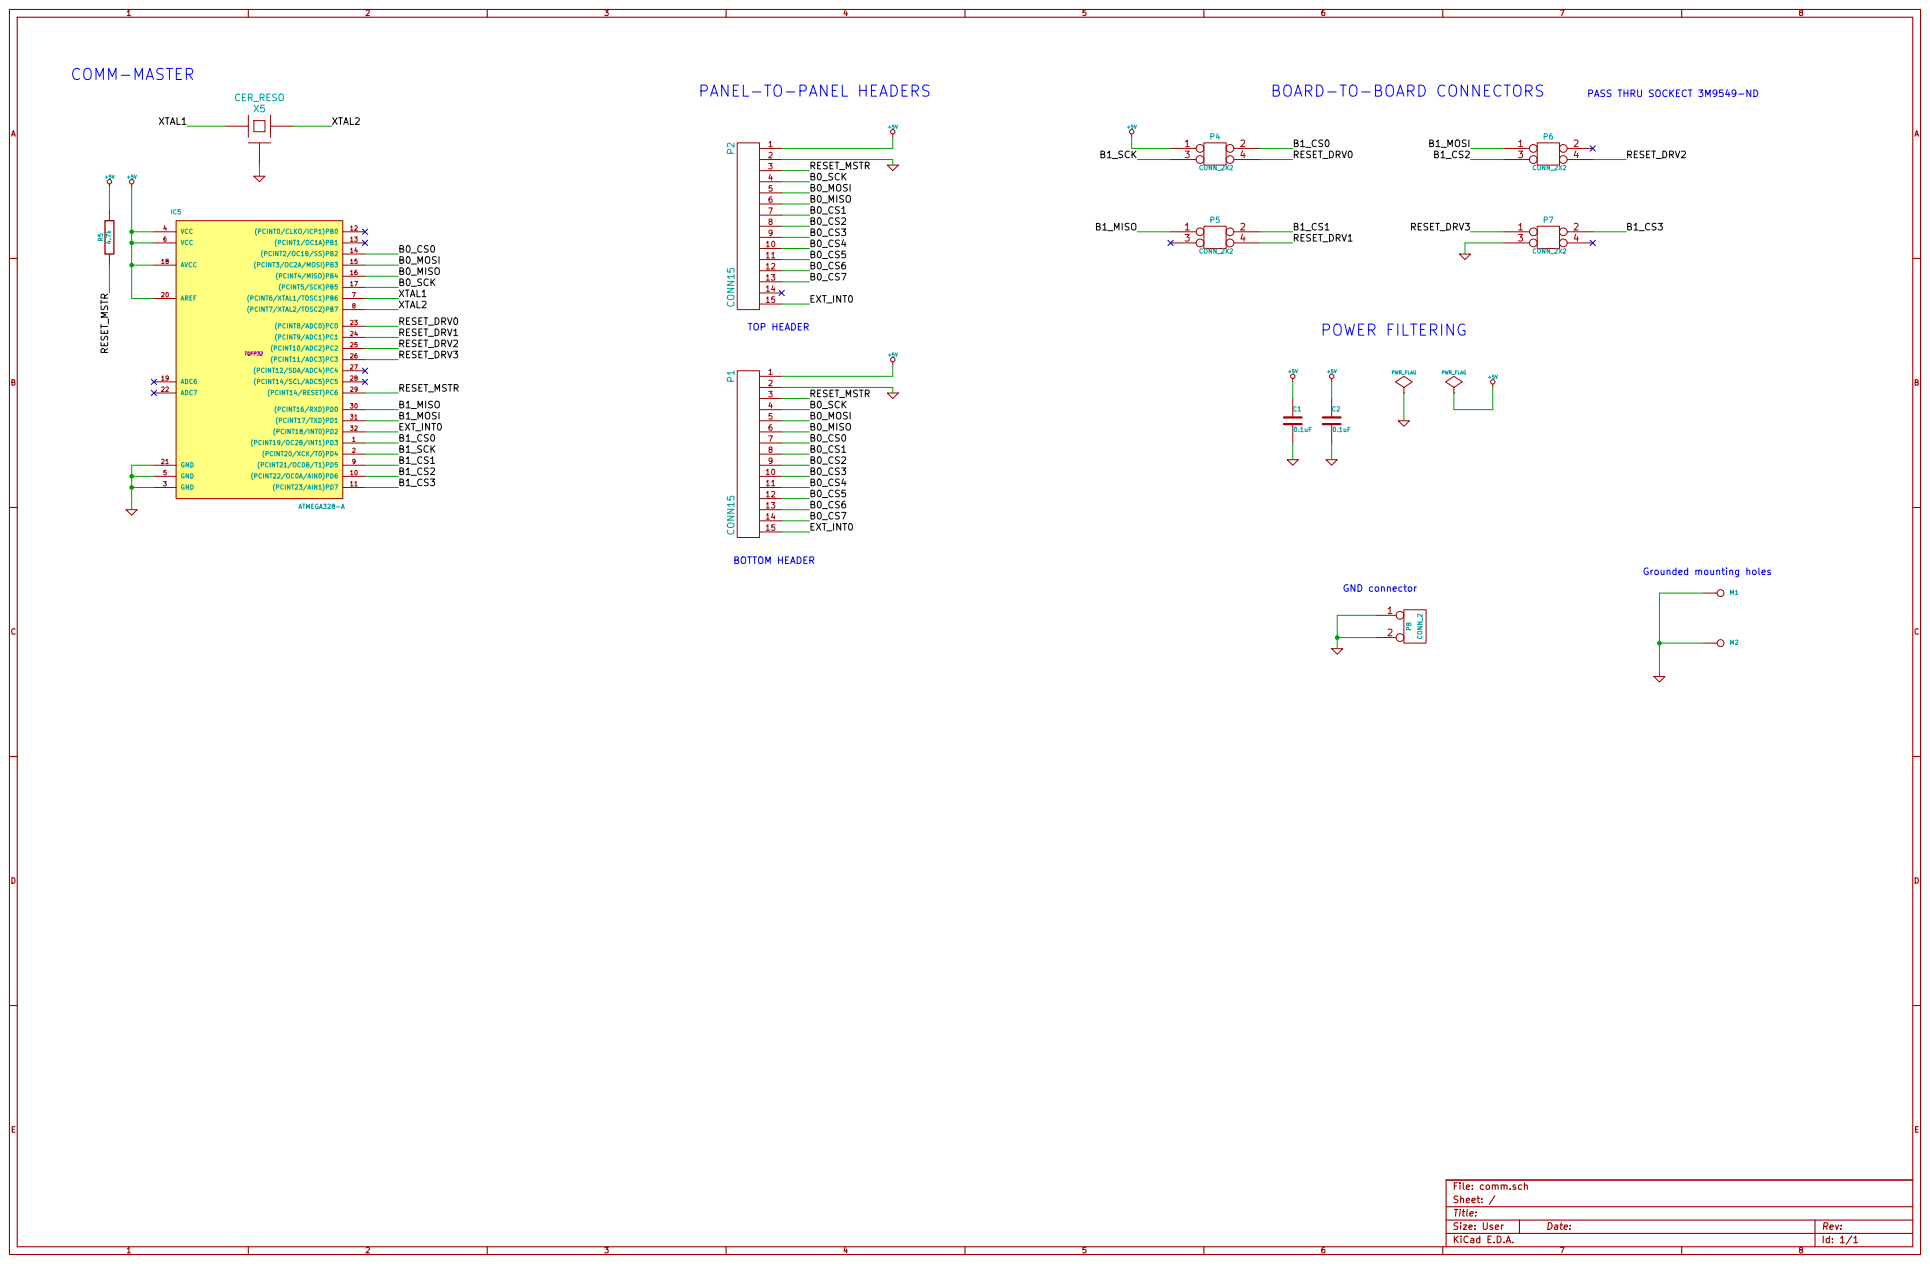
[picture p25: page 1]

PANEL-TO-PANEL HEADERS
15 P2 CONN15

BOARD-TO-BOARD CONNECTORS

PASS THRU SOCKECT 3M9549-ND

Id: 1/1 Title: File: comm.sch Sheet: /

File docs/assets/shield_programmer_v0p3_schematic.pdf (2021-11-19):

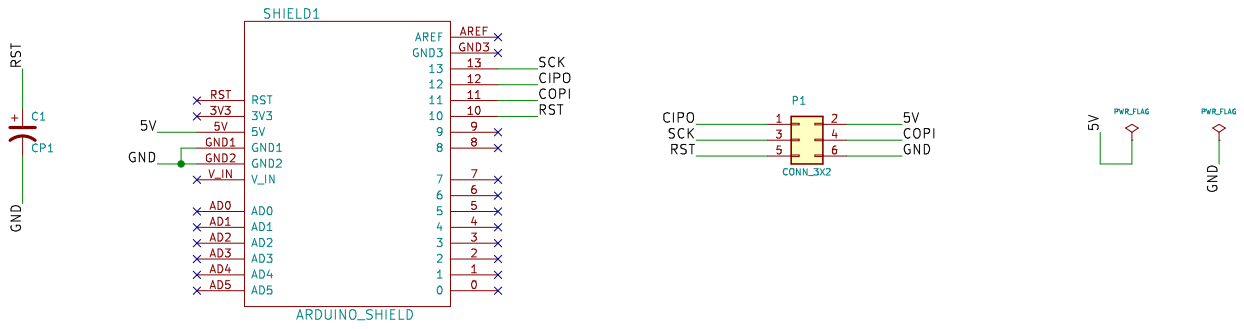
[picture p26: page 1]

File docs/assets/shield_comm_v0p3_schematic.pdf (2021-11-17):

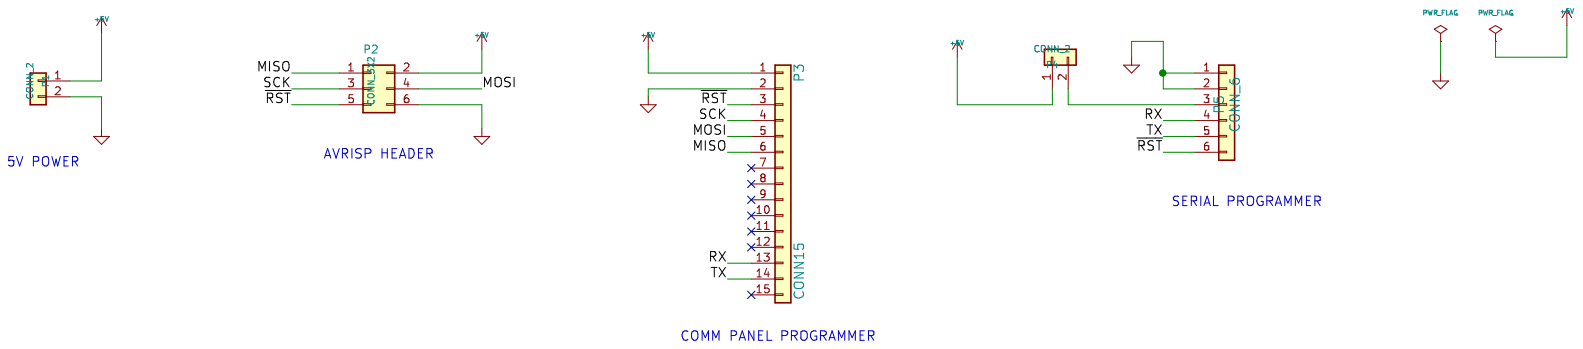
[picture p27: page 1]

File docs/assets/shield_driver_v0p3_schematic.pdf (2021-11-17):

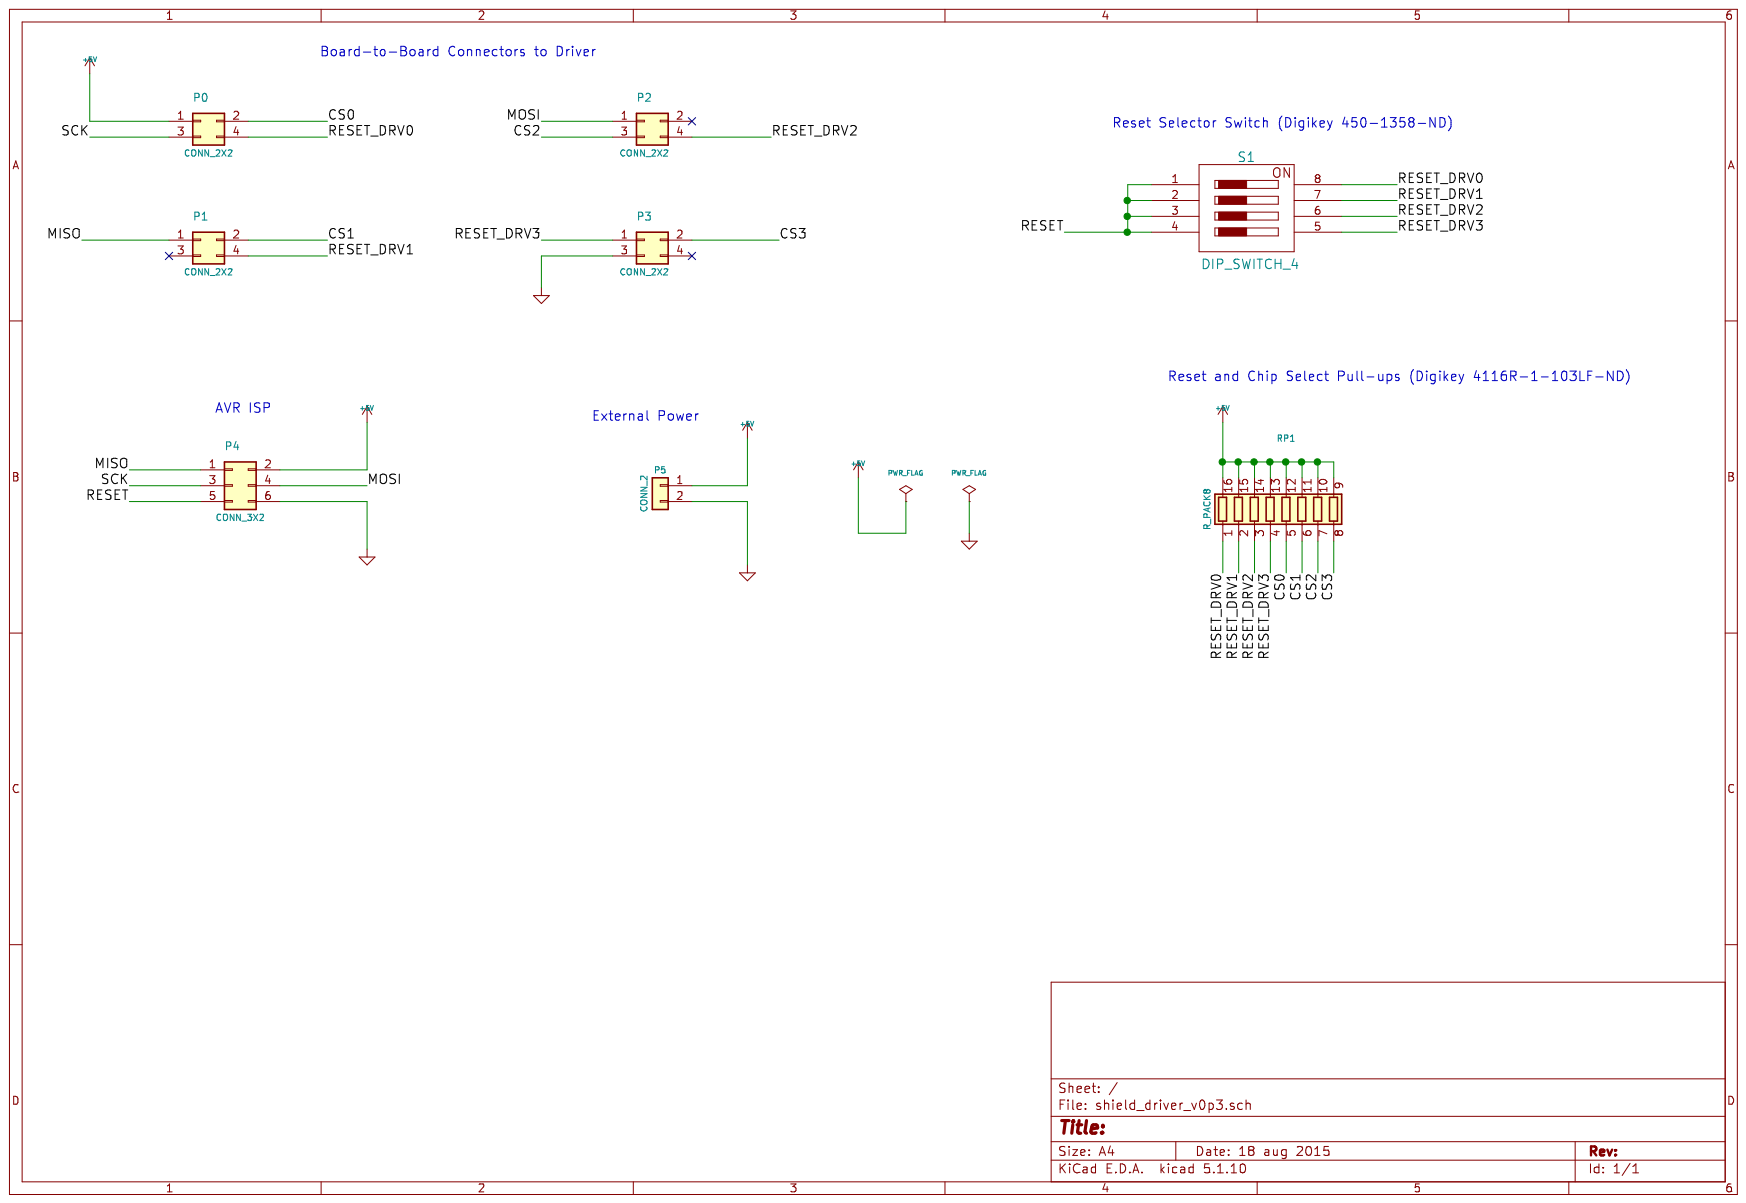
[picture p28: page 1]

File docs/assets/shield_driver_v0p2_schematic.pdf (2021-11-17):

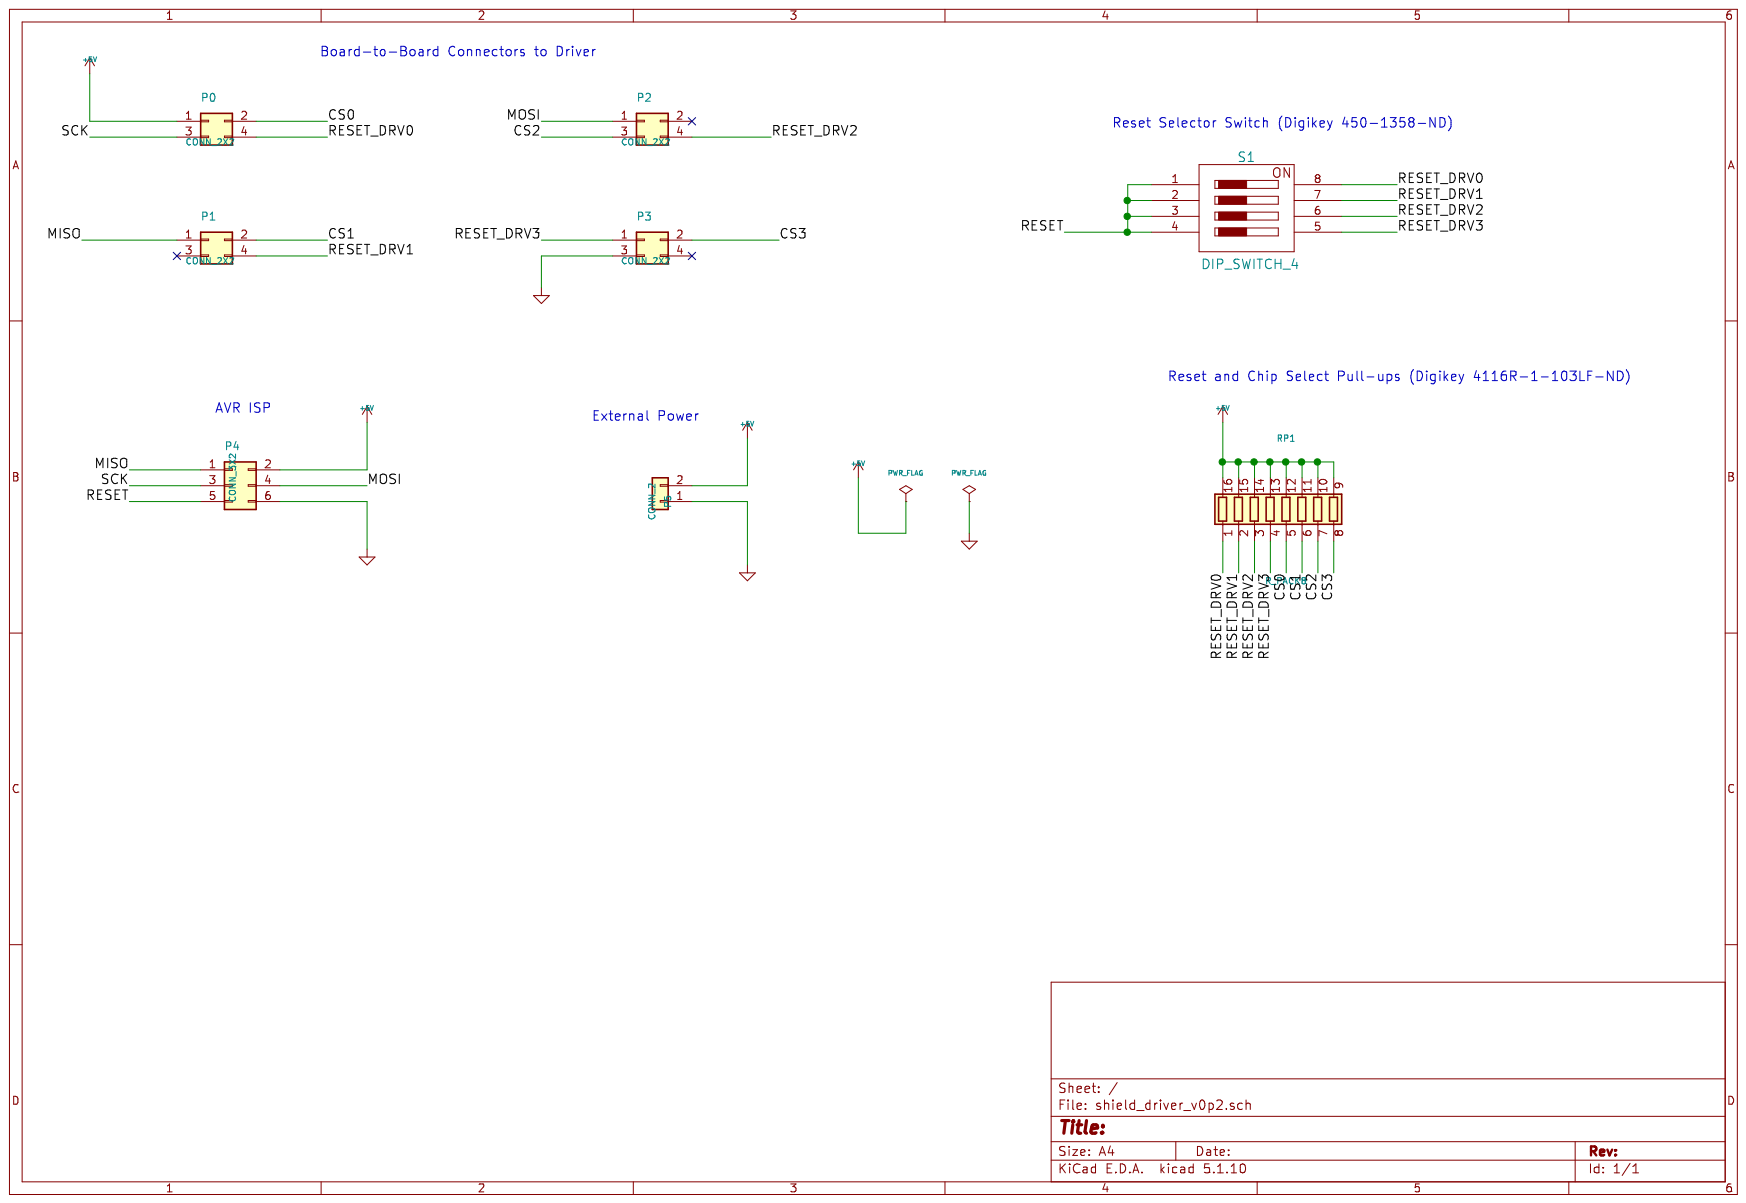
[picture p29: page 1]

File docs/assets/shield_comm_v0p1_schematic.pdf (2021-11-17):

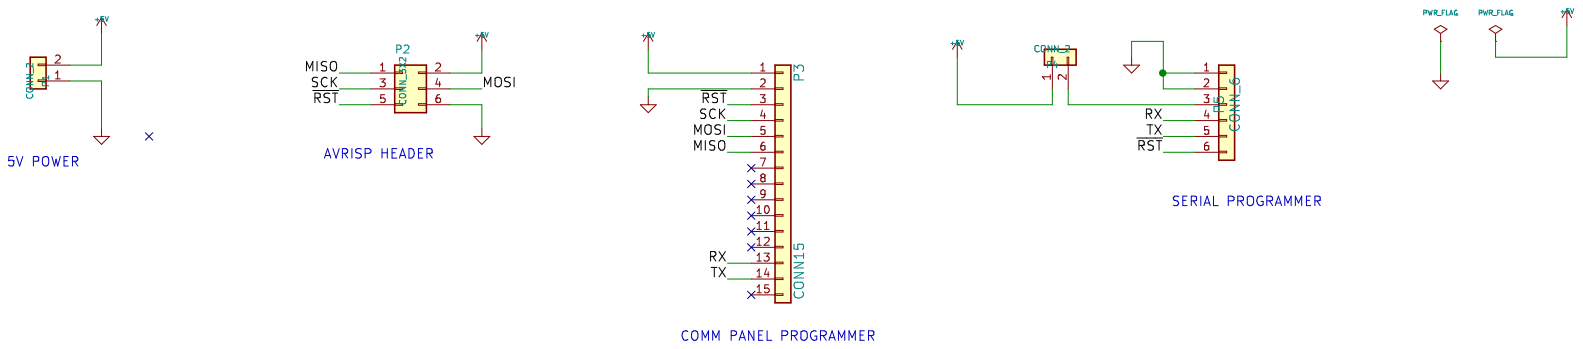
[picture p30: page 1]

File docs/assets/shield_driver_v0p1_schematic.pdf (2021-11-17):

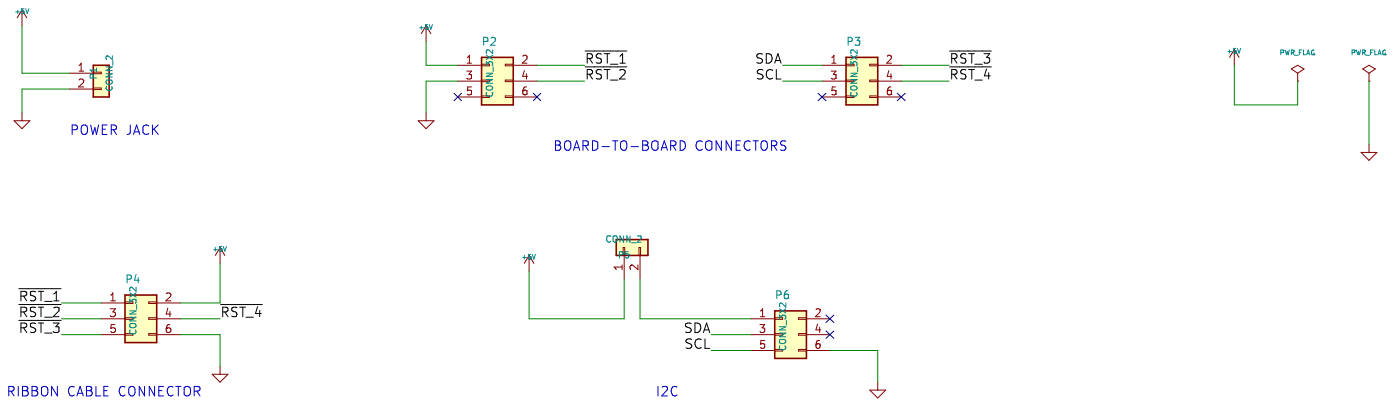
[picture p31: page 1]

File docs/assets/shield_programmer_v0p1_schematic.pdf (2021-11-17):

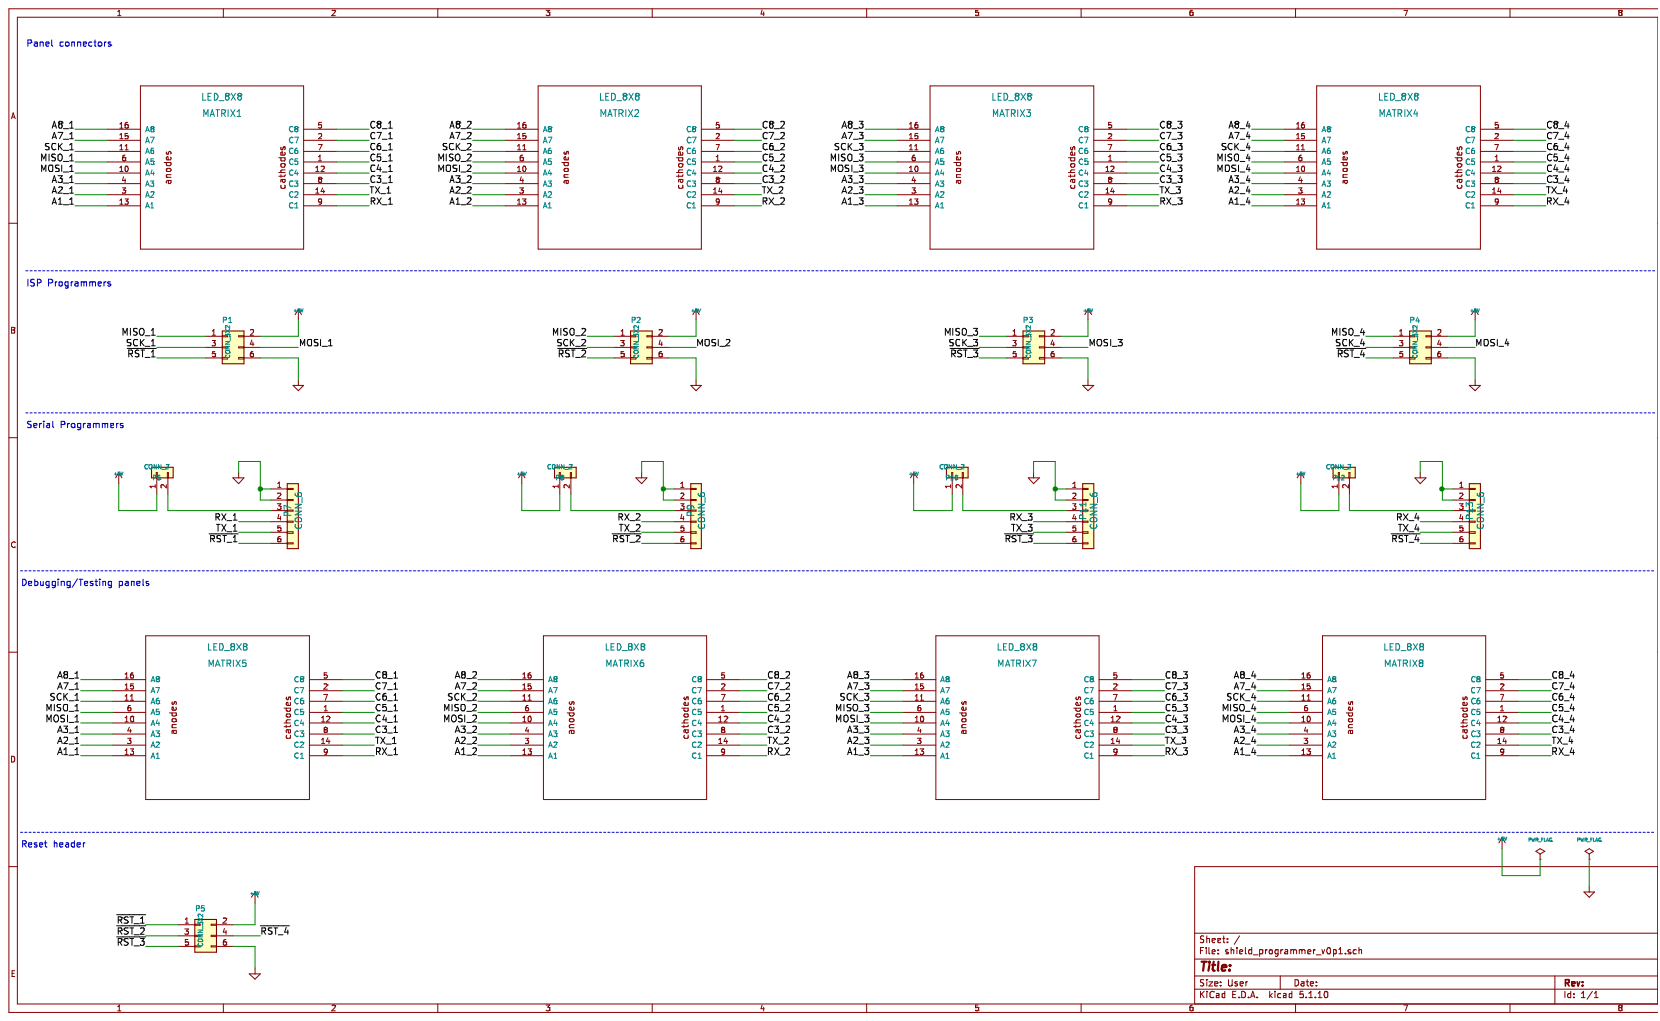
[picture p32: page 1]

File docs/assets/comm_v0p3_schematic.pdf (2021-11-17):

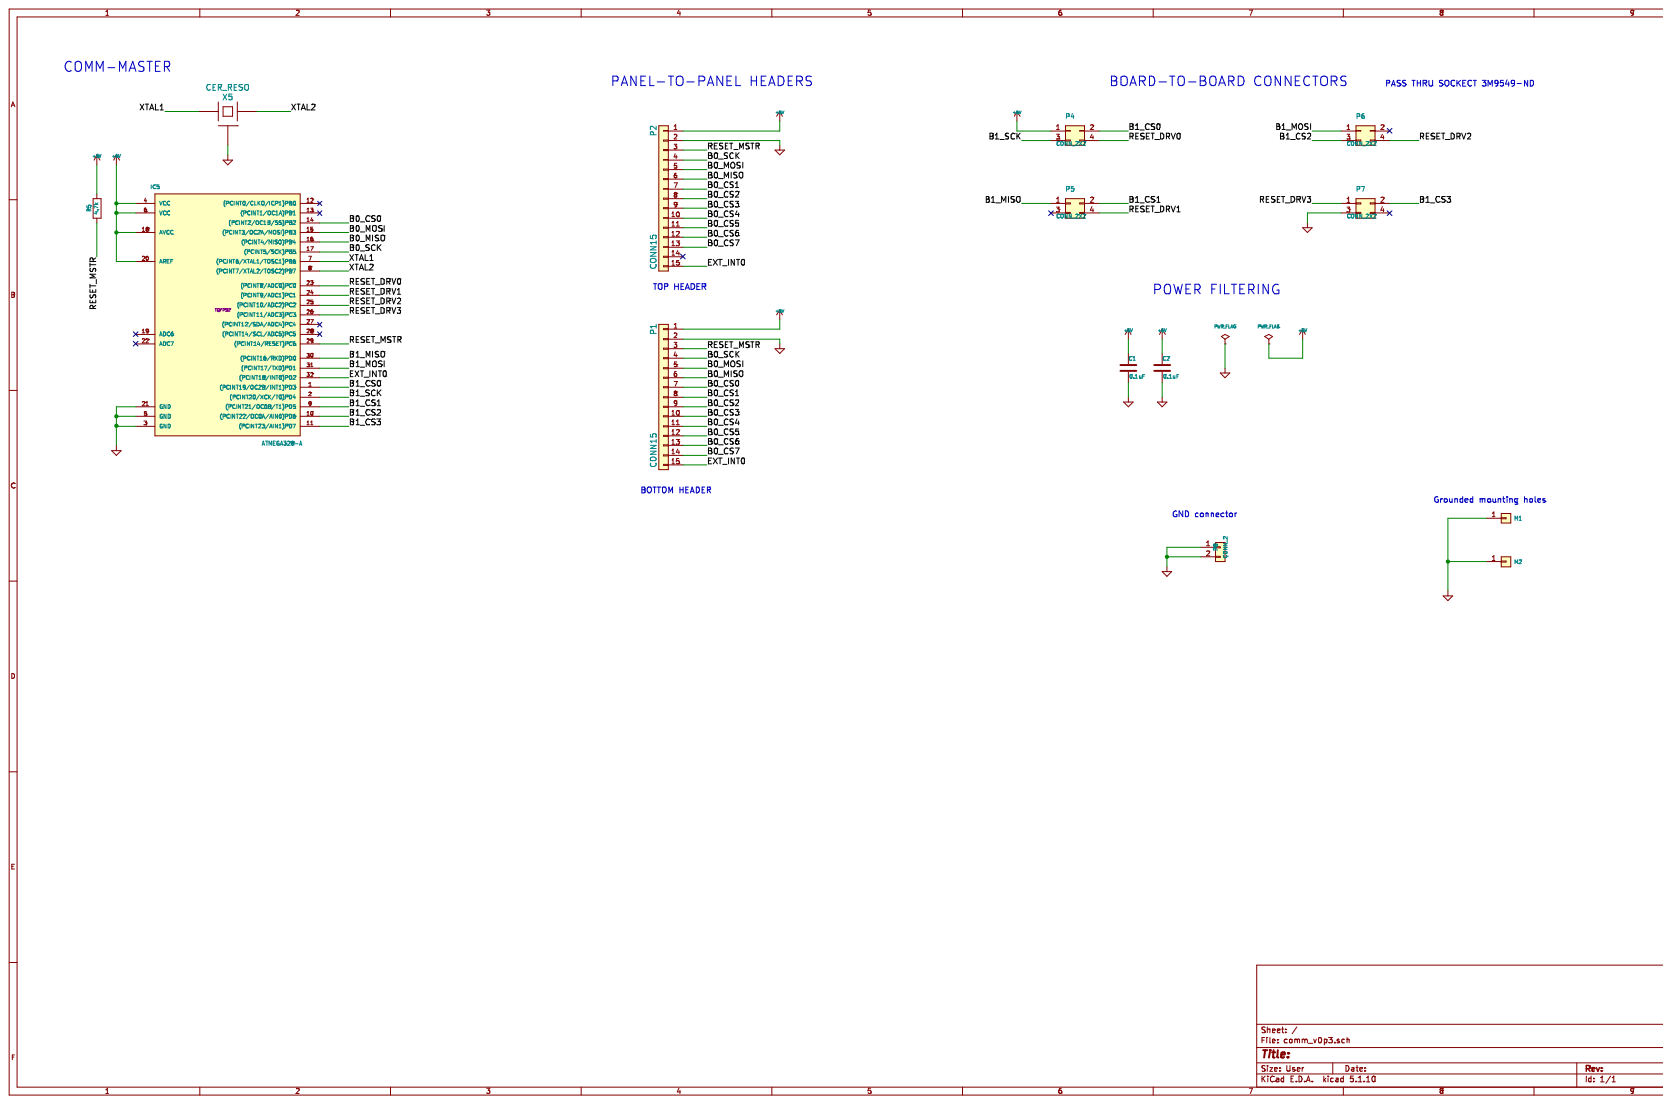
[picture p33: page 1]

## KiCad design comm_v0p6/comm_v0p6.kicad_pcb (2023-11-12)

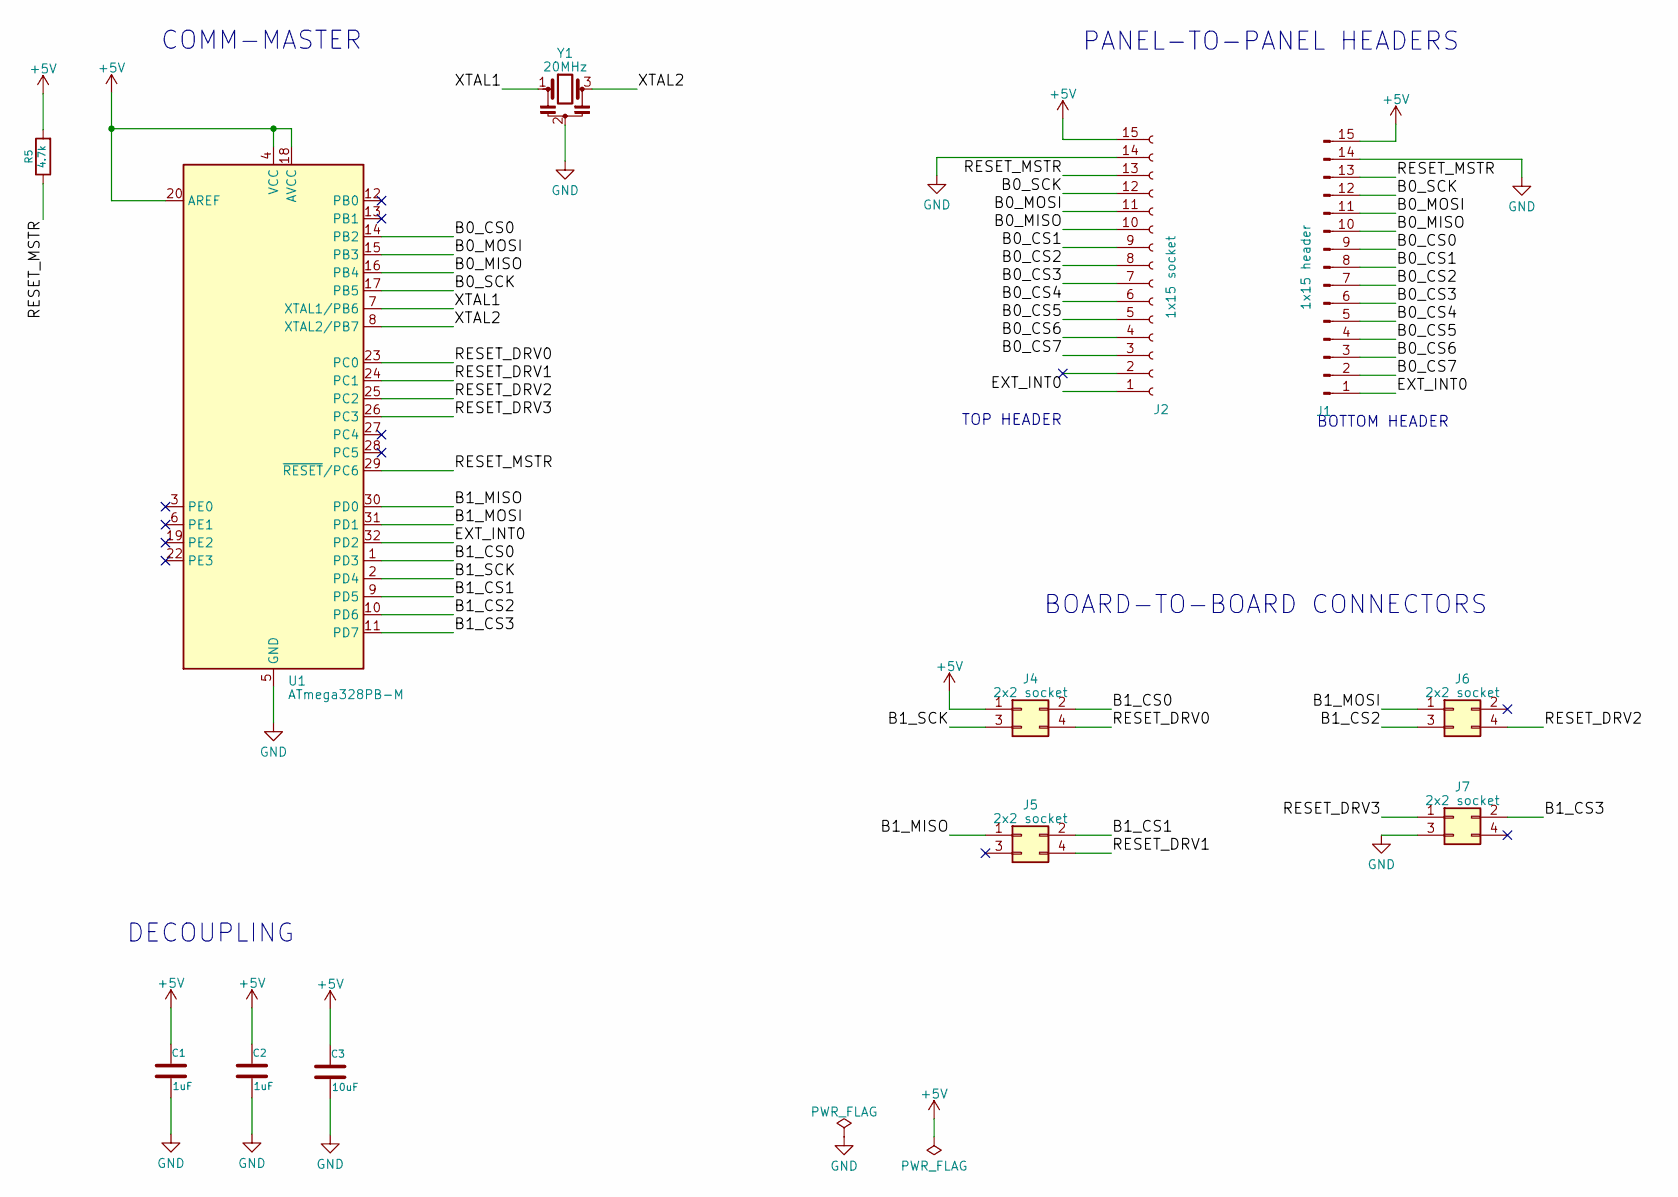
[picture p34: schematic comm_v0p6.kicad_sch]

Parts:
C1, C2: 1uF; C_0402_1005Metric; DigiKey PN 1276-1067-1-ND
C3: 10uF; C_0805_2012Metric; DigiKey PN 1276-1067-1-ND
J1: 1x15 header; PinHeader_1x15_P2.54mm_Horizontal; DigiKey PN 2057-PH1RB-15-UA-ND
J2: 1x15 socket; PinSocket_1x15_P2.54mm_Horizontal; DigiKey PN 612-SSQ-115-02-G-S-RA-ND
J4, J5, J6, J7: 2x2 socket; PinSocket_2x02_P2.54mm_Vertical; DigiKey PN A125237-ND
R5: 4.7k; R_0603_1608Metric; DigiKey PN 311-4.7KGRCT-ND
U1: ATmega328PB-M; QFN-32-1EP_5x5mm_P0.5mm_EP3.1x3.1mm; DigiKey PN ATMEGA328PB-MURCT-ND
Y1: 20MHz; Resonator_SMD_Murata_CSTxExxV-3Pin_3.0x1.1mm; DigiKey PN 490-17953-1-ND

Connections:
+5V: C1.1, C2.1, C3.1, J1.15, J2.15, J4.1, R5.2, U1.4 (VCC), U1.18 (AVCC), U1.20 (AREF)
/B0_CS0: J1.9, U1.14 (PB2)
/B0_CS1: J1.8, J2.9
/B0_CS2: J1.7, J2.8
/B0_CS3: J1.6, J2.7
/B0_CS4: J1.5, J2.6
/B0_CS5: J1.4, J2.5
/B0_CS6: J1.3, J2.4
/B0_CS7: J1.2, J2.3
/B0_MISO: J1.10, J2.10, U1.16 (PB4)
/B0_MOSI: J1.11, J2.11, U1.15 (PB3)
/B0_SCK: J1.12, J2.12, U1.17 (PB5)
/B1_CS0: J4.2, U1.1 (PD3)
/B1_CS1: J5.2, U1.9 (PD5)
/B1_CS2: J6.3, U1.10 (PD6)
/B1_CS3: J7.2, U1.11 (PD7)
/B1_MISO: J5.1, U1.30 (PD0)
/B1_MOSI: J6.1, U1.31 (PD1)
/B1_SCK: J4.3, U1.2 (PD4)
/EXT_INT0: J1.1, J2.1, U1.32 (PD2)
/RESET_DRV0: J4.4, U1.23 (PC0)
/RESET_DRV1: J5.4, U1.24 (PC1)
/RESET_DRV2: J6.4, U1.25 (PC2)
/RESET_DRV3: J7.1, U1.26 (PC3)
/RESET_MSTR: J1.13, J2.13, R5.1, U1.29 (~RESET/PC6)
/XTAL1: U1.7 (XTAL1/PB6), Y1.1
/XTAL2: U1.8 (XTAL2/PB7), Y1.3
GND: C1.2, C2.2, C3.2, J1.14, J2.14, J7.3, U1.5 (GND), U1.21 (GND), U1.33 (GND), Y1.2

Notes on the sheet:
PANEL-TO-PANEL HEADERS
TOP HEADER
COMM-MASTER
DECOUPLING
BOTTOM HEADER
BOARD-TO-BOARD CONNECTORS

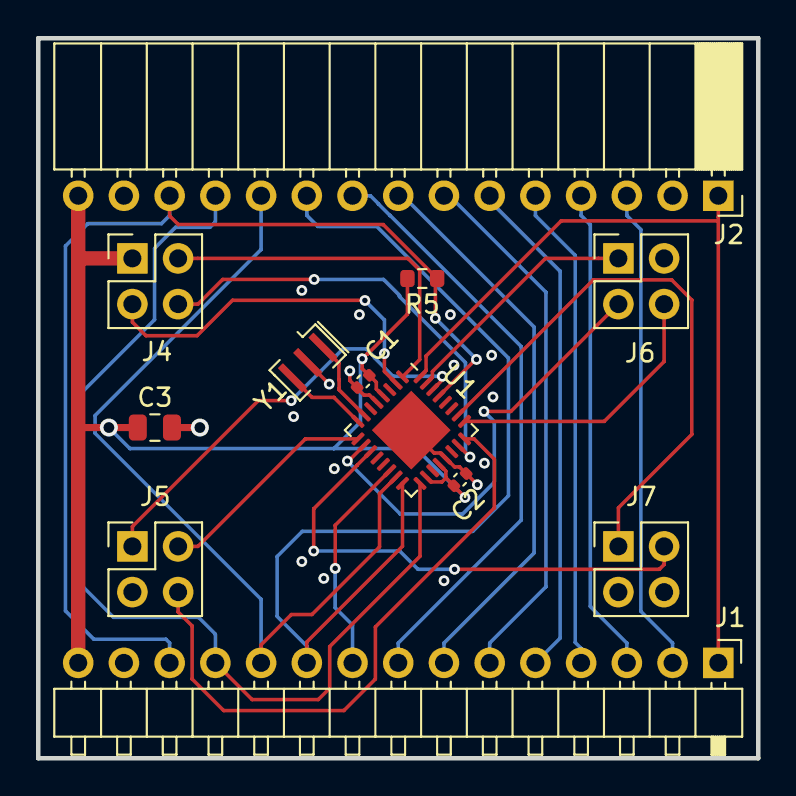
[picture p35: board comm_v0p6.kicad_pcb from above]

Board: 4 copper layers, 40.0 x 40.0 mm, 12 parts (0 on the bottom side), 28 nets.

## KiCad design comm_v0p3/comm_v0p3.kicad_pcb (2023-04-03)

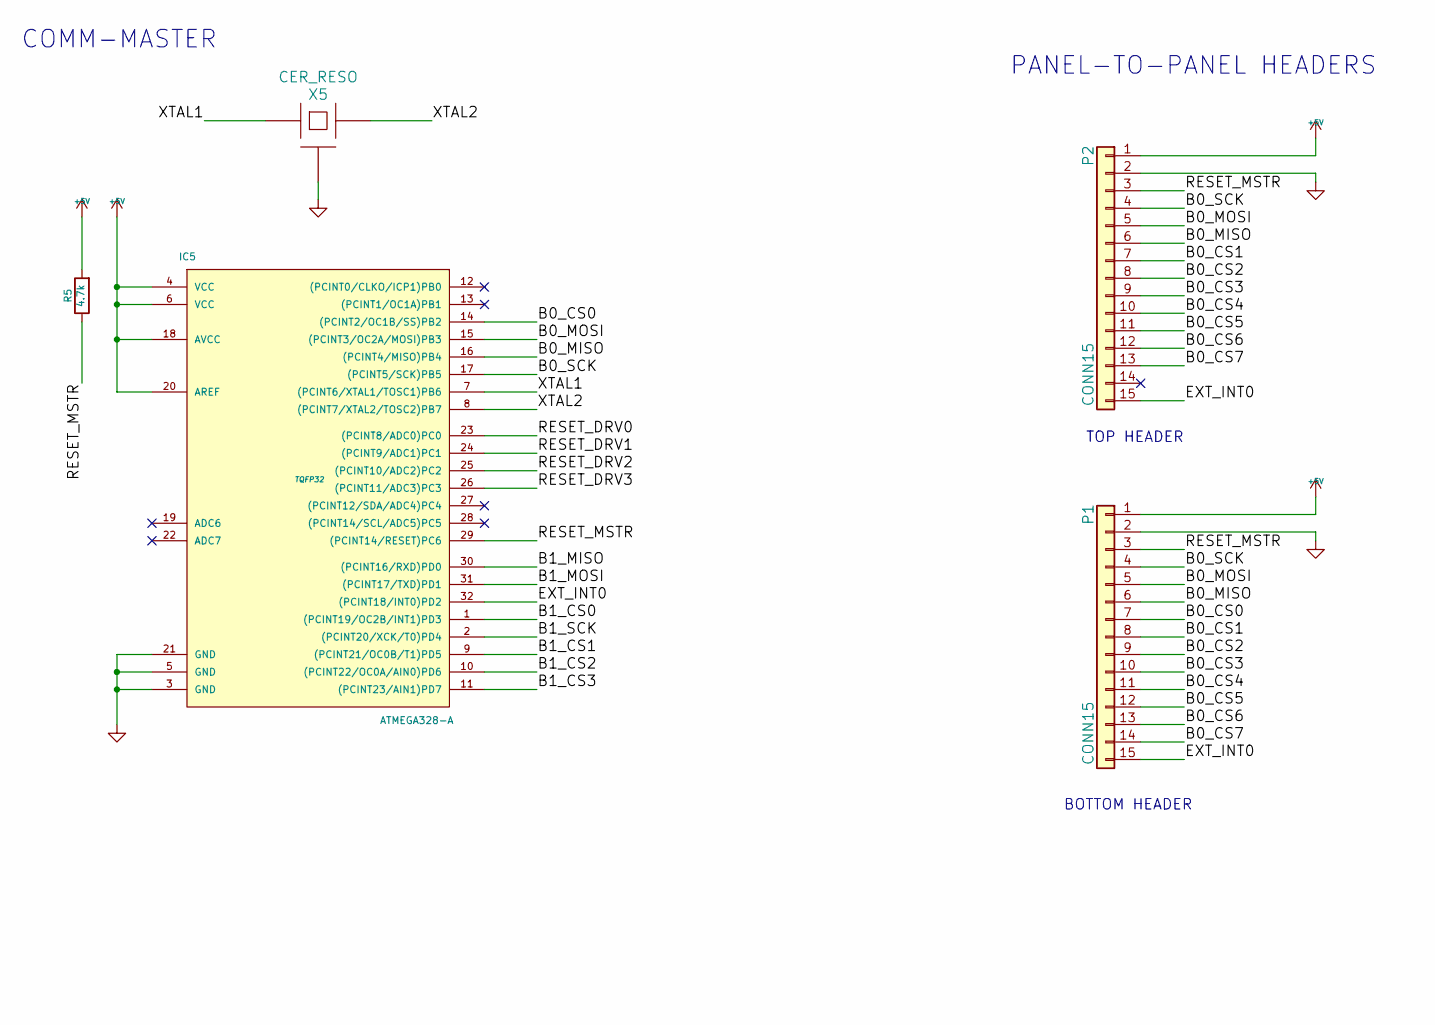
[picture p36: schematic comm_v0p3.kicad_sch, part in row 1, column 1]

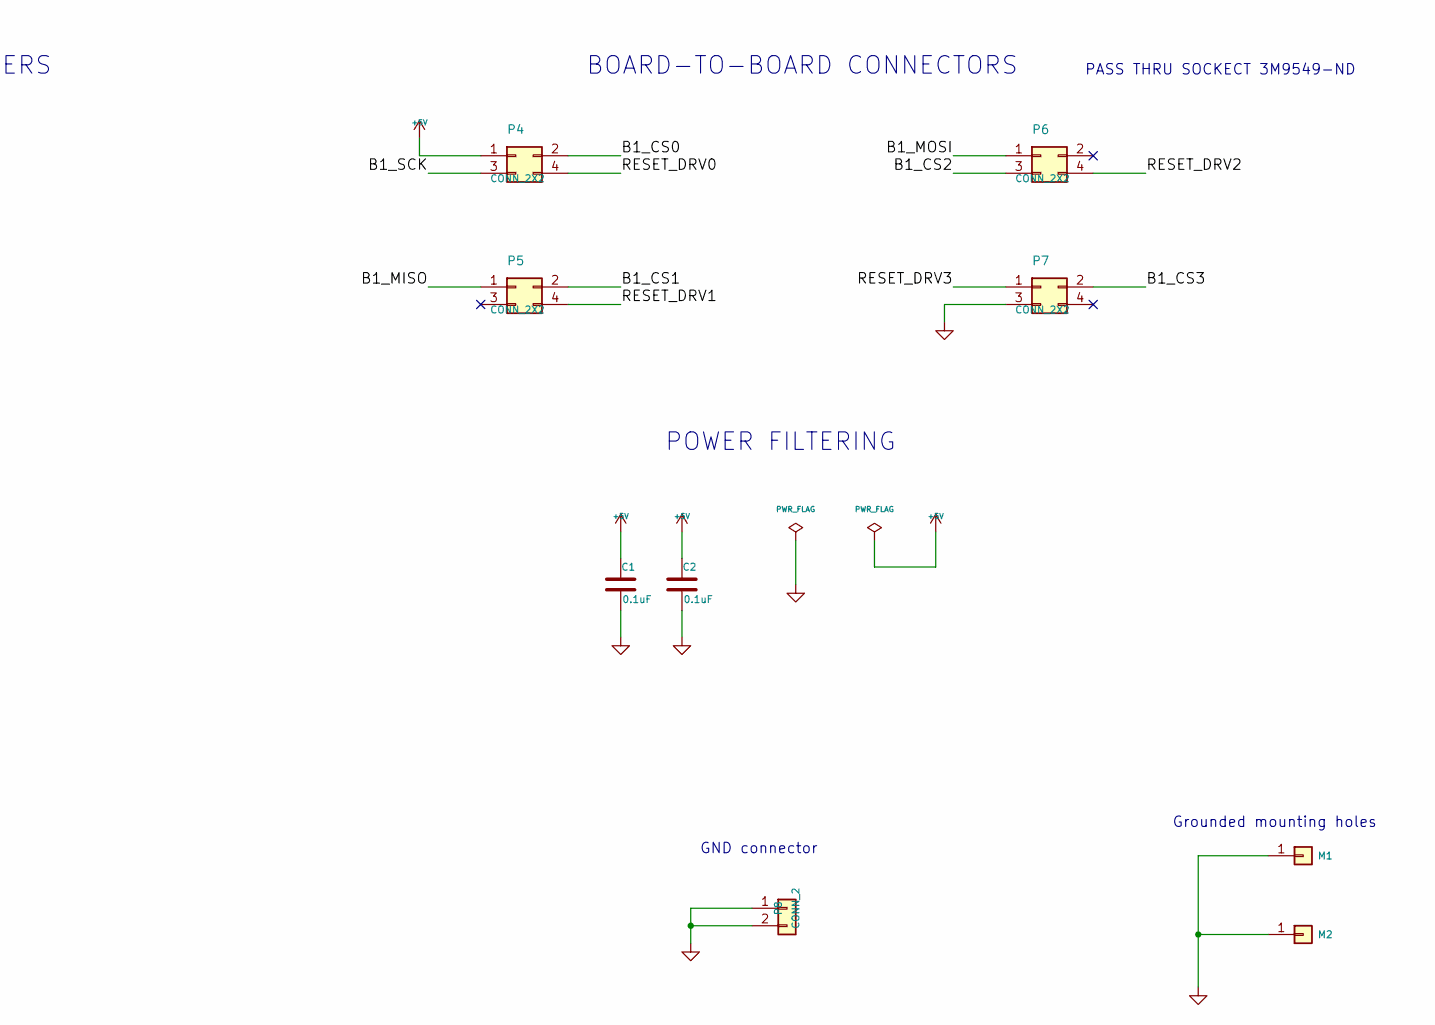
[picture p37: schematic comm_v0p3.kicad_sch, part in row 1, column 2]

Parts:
C1, C2: 0.1uF
IC5: ATMEGA328-A; TQFP32
M1, M2: CONN_1
P1, P2: CONN15
P4, P5, P6, P7: CONN_2X2
P8: CONN_2
R5: 4.7k
X5: CER_RESO

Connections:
+5V: C1.1, C2.1, IC5.4 (VCC), IC5.6 (VCC), IC5.18 (AVCC), IC5.20 (AREF), P1.1, P2.1, P4.1, R5.2
/B0_CS0: IC5.14 ((PCINT2/OC1B/SS)PB2), P1.7
/B0_CS1: P1.8, P2.7
/B0_CS2: P1.9, P2.8
/B0_CS3: P1.10, P2.9
/B0_CS4: P1.11, P2.10
/B0_CS5: P1.12, P2.11
/B0_CS6: P1.13, P2.12
/B0_CS7: P1.14, P2.13
/B0_MISO: IC5.16 ((PCINT4/MISO)PB4), P1.6, P2.6
/B0_MOSI: IC5.15 ((PCINT3/OC2A/MOSI)PB3), P1.5, P2.5
/B0_SCK: IC5.17 ((PCINT5/SCK)PB5), P1.4, P2.4
/B1_CS0: IC5.1 ((PCINT19/OC2B/INT1)PD3), P4.2
/B1_CS1: IC5.9 ((PCINT21/OC0B/T1)PD5), P5.2
/B1_CS2: IC5.10 ((PCINT22/OC0A/AIN0)PD6), P6.3
/B1_CS3: IC5.11 ((PCINT23/AIN1)PD7), P7.2
/B1_MISO: IC5.30 ((PCINT16/RXD)PD0), P5.1
/B1_MOSI: IC5.31 ((PCINT17/TXD)PD1), P6.1
/B1_SCK: IC5.2 ((PCINT20/XCK/T0)PD4), P4.3
/EXT_INT0: IC5.32 ((PCINT18/INT0)PD2), P1.15, P2.15
/RESET_DRV0: IC5.23 ((PCINT8/ADC0)PC0), P4.4
/RESET_DRV1: IC5.24 ((PCINT9/ADC1)PC1), P5.4
/RESET_DRV2: IC5.25 ((PCINT10/ADC2)PC2), P6.4
/RESET_DRV3: IC5.26 ((PCINT11/ADC3)PC3), P7.1
/RESET_MSTR: IC5.29 ((PCINT14/RESET)PC6), P1.3, P2.3, R5.1
/XTAL1: IC5.7 ((PCINT6/XTAL1/TOSC1)PB6), X5.1
/XTAL2: IC5.8 ((PCINT7/XTAL2/TOSC2)PB7), X5.3
GND: C1.2, C2.2, IC5.3 (GND), IC5.5 (GND), IC5.21 (GND), M1.1, M2.1, P1.2, P2.2, P7.3, P8.1, P8.2, X5.2 (GND)

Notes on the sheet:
Grounded mounting holes
PANEL-TO-PANEL HEADERS
GND connector
TOP HEADER
COMM-MASTER
POWER FILTERING
BOTTOM HEADER
PASS THRU SOCKECT 3M9549-ND
BOARD-TO-BOARD CONNECTORS

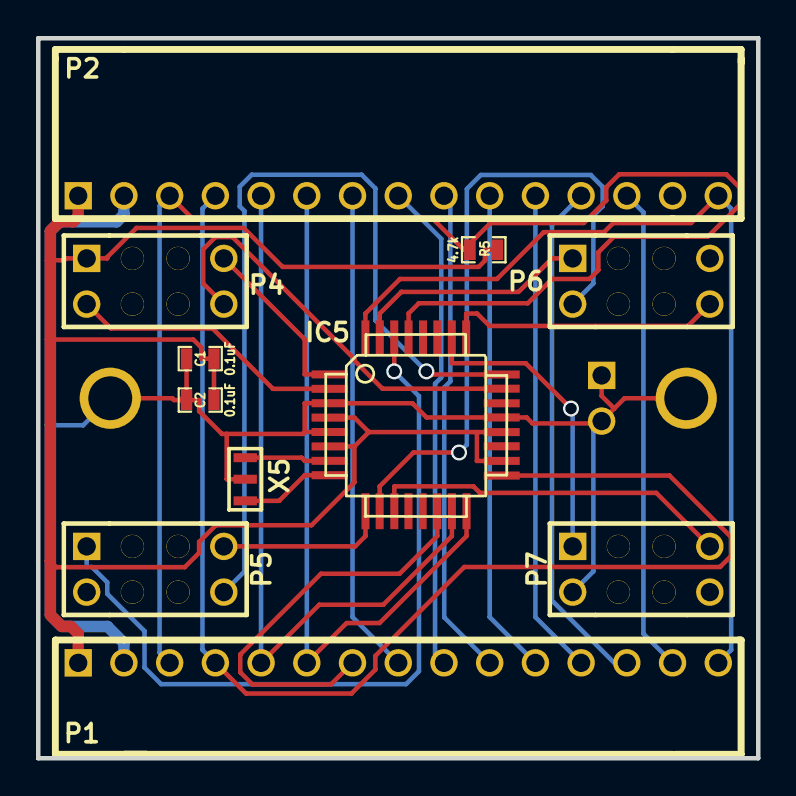
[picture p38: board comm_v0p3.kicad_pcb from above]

Board: 2 copper layers, 40.0 x 40.0 mm, 14 parts (1 on the bottom side), 28 nets.

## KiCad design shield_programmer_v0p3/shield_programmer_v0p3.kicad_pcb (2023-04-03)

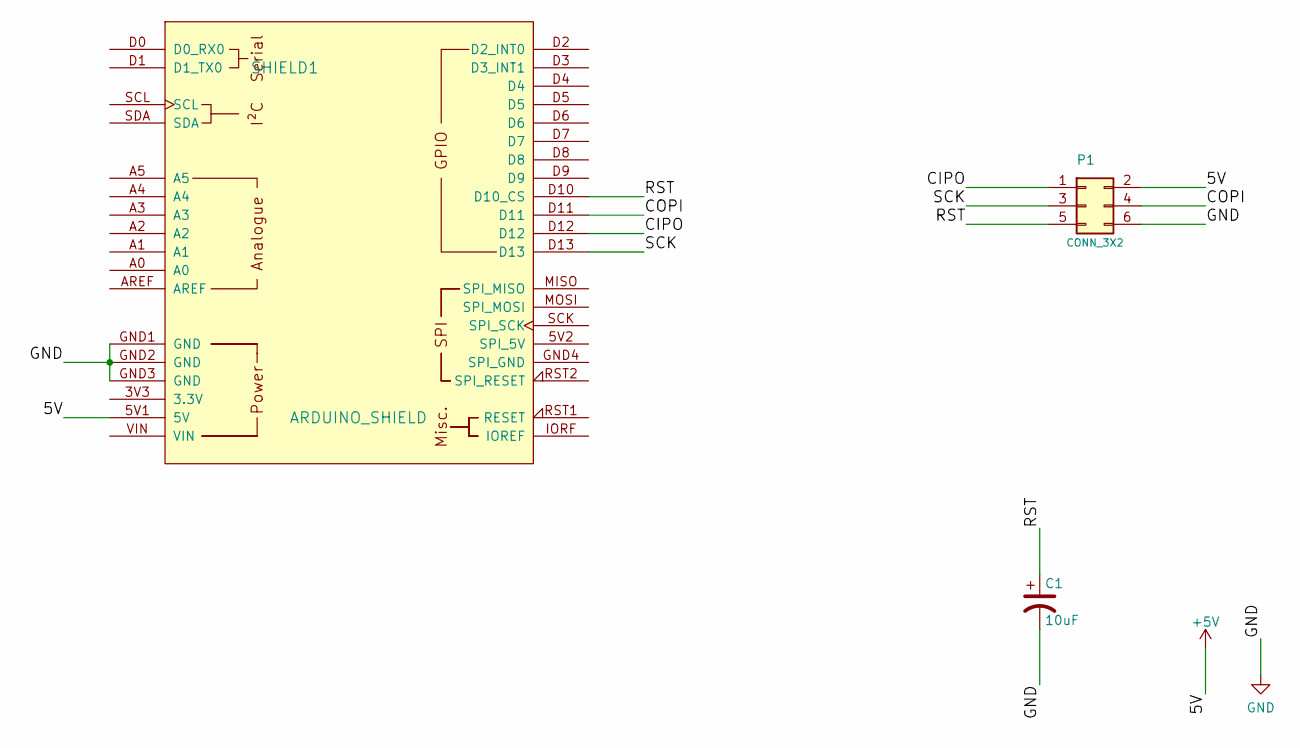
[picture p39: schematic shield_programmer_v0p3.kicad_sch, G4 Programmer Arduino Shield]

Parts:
C1: 10uF; CP_Radial_D10.0mm_P5.00mm
P1: CONN_3X2; PinHeader_2x03_P2.54mm_Vertical
SHIELD1: ARDUINO_SHIELD; Arduino_Zero_Shield

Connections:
+5V: P1.2, SHIELD1.5V1 (5V)
/CIPO: P1.1, SHIELD1.D12
/COPI: P1.4, SHIELD1.D11
/RST: C1.1, P1.5, SHIELD1.D10 (D10_CS)
/SCK: P1.3, SHIELD1.D13
GND: C1.2, P1.6, SHIELD1.GND1 (GND), SHIELD1.GND2 (GND), SHIELD1.GND3 (GND)

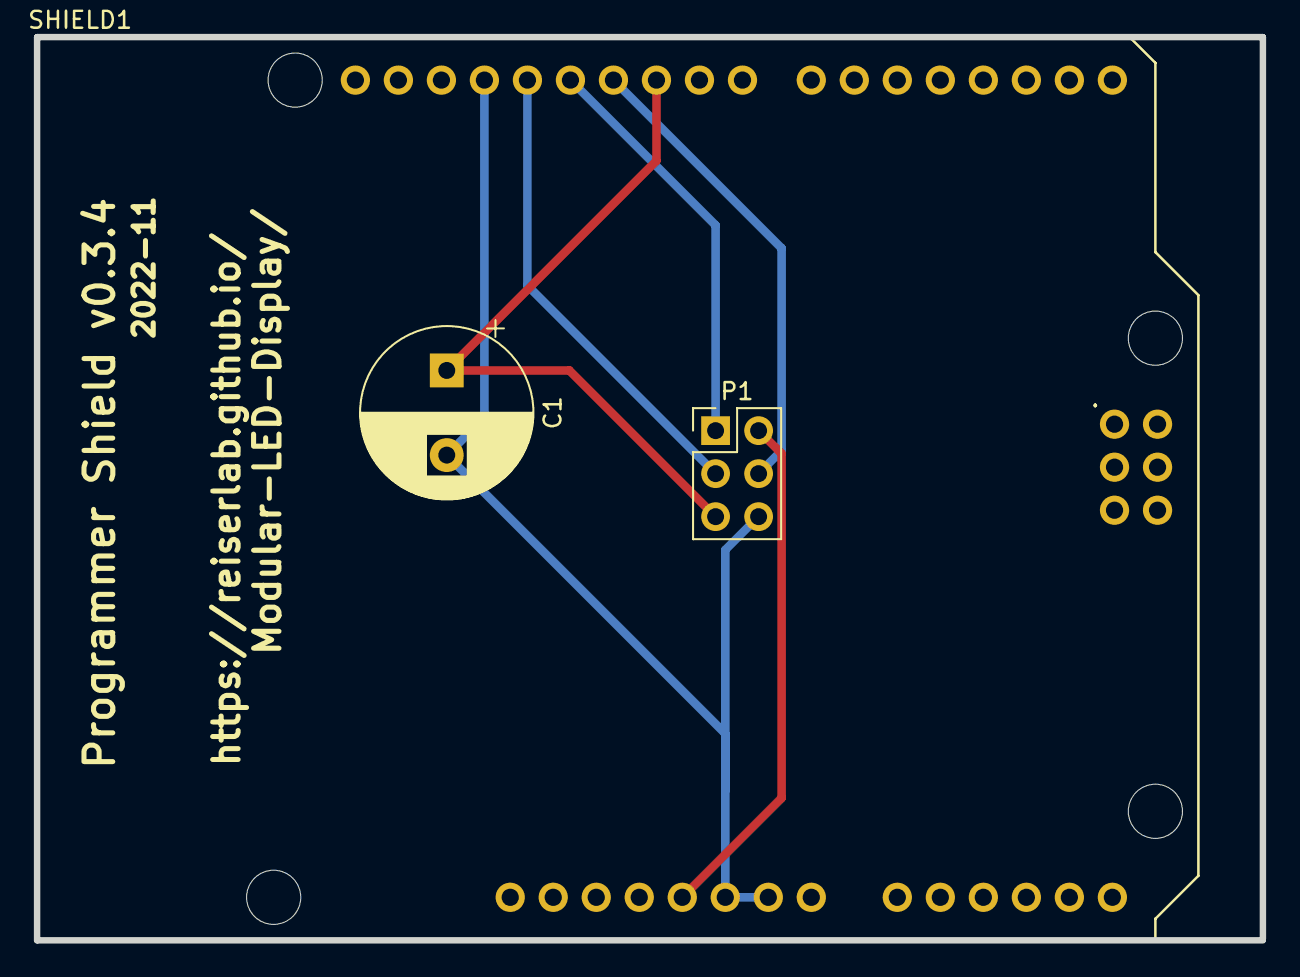
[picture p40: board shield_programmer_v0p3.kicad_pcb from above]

Board: 2 copper layers, 72.4 x 53.3 mm, 3 parts (0 on the bottom side), 6 nets.

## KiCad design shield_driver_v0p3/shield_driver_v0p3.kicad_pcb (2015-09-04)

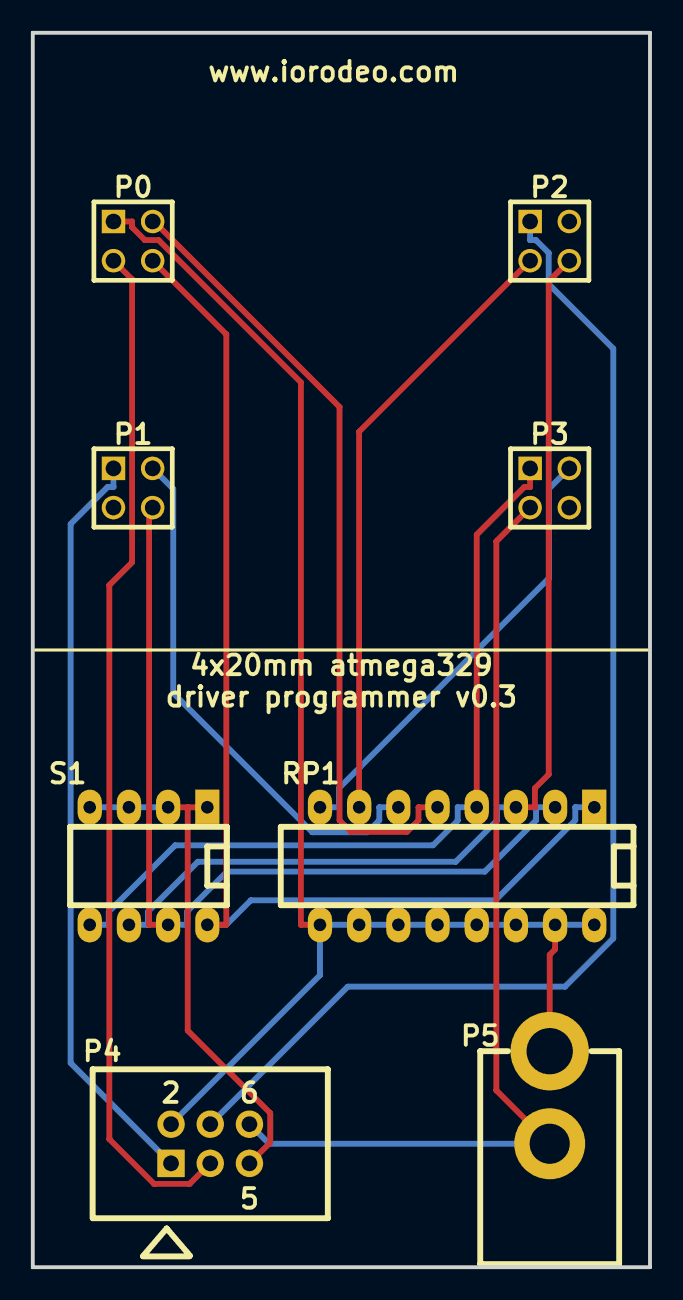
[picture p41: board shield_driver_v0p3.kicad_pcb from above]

Board: 2 copper layers, 40.0 x 80.0 mm, 8 parts (0 on the bottom side), 14 nets.

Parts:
P0, P1, P2, P3: CONN_2X2; PIN_ARRAY_2X2
P4: CONN_3X2; 3X2_SHRD_HEADER
P5: CONN_2; DCJACK_2PIN
RP1: R_PACK8; DIP-16__300_ELL
S1: DIP_SWITCH_4; DIP-8__300_ELL

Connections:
+5V: P0.1, P4.2, P5.1, RP1.9, RP1.10, RP1.11, RP1.12, RP1.13, RP1.14, RP1.15, RP1.16
/CS0: P0.2, RP1.5
/CS1: P1.2, RP1.6
/CS2: P2.3, RP1.7
/CS3: P3.2, RP1.8
/MISO: P1.1, P4.1
/MOSI: P2.1, P4.4
/RESET: P4.5, S1.1, S1.2, S1.3, S1.4
/RESET_DRV0: P0.4, RP1.1, S1.8
/RESET_DRV1: P1.4, RP1.2, S1.7
/RESET_DRV2: P2.4, RP1.3, S1.6
/RESET_DRV3: P3.1, RP1.4, S1.5
/SCK: P0.3, P4.3
GND: P3.3, P4.6, P5.2

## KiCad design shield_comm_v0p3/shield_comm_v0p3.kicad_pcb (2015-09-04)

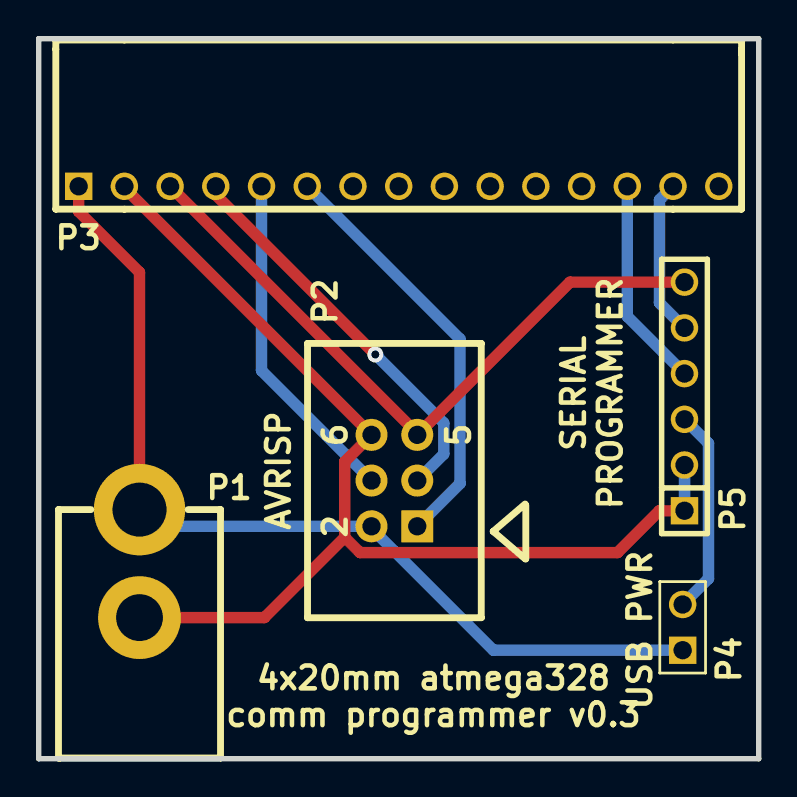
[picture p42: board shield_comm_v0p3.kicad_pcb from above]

Board: 2 copper layers, 40.0 x 40.0 mm, 5 parts (0 on the bottom side), 9 nets.

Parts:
P1: CONN_2; DCJACK_2PIN
P2: CONN_3X2; 3X2_SHRD_HEADER
P3: CONN15; HEADER_TOP
P4: CONN_2; PIN_ARRAY_2X1
P5: CONN_6; PIN_ARRAY-6X1

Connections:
+5V: P1.1, P2.2, P3.1, P4.1
/MISO: P2.1, P3.6
/MOSI: P2.4, P3.5
/RX: P3.13, P5.4
/SCK: P2.3, P3.4
/TX: P3.14, P5.5
/~RST: P2.5, P3.3, P5.6
GND: P1.2, P2.6, P3.2, P5.1, P5.2
unnamed: P4.2, P5.3

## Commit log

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2013-02-02 work in progress for the pcb schematic design.
    [LEDs.sch, STM32.sch, conn.sch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]
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2013-04-07 Simplified big stm32 based panel design. Completed schematic for max6960 based panel.
    [$savepcb.brd, BOM.xls, LEDs.sch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]
2013-04-07 Completed initial design of panels (G4) based on the max6960 IC. Created adapter PCB for mounting two 8x8 panels to max6960 controller board. Created version 0.1 of gerber files for both the controll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
    [$savepcb.brd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]
2013-04-10 Worked one one panel 4bit grey scale max6960 panel schematic.
    [$savepcb.brd, LEDs.sch, STM32.sch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]
2013-04-12 Added new one panel version of the max6960 design.
    [$savepcb.brd, adapter.brd, adapter.dsn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]
2013-04-12 Re-arrange project - added sub-directories for stm32 and max6960 based designs, etc.
    [$savepcb.brd, BOM.xls, LEDs.sch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]
2013-04-12 Added adapter for two panel design for testing with one matrix in 4bit intensity scale mode.
    [one_panel_adapter.brd, one_panel_adapter.dsn, one_panel_adapter.sch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]
2013-04-12 Added one panel 4bit intesity scale adpater pcb to w/ diodes.
    [one_panel_adapter.brd, one_panel_adapter.dsn, one_panel_adapter.sch]
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2013-08-05 Modifed four_panel pcbs for newer kicad pcb board format.
    [$savepcb.brd, adapter.brd, adapter.kicad_pcb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]
2013-08-06 Finished preliminary versions of driver and adapter pcbs for the max6860 four 20mm 8x8 led matrix panels.
    [adapter.dsn, adapter.kicad_pcb, adapter.sch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]
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2013-08-14 Re-routed four matrix panel driver and adapter. Switched to board-to-board connectors from major league.
    [adapter.dsn, adapter.kicad_pcb, adapter.sch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]
2013-08-19 Created 2 and 4 layer versions of the adapeter PCB.
    [adapter.dsn, adapter.kicad_pcb, adapter.sch]
2013-08-19 Added re-routed 2-layer versionf of four panel max6960 design.
    [adapter.dsn, adapter.kicad_pcb, adapter.sch]
2013-08-19 Added atmega328 design for 1 32mm led matrix.
    [flypanels.brd, flypanels.dsn, flypanels.kicad_pcb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]
2013-08-19 Moved one panel atmega328 based design to 32mm_matrix sub-folder.
    [flypanels.brd, flypanels.dsn, flypanels.kicad_pcb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]
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2013-08-20 Worked on 4x 20mm led matrix atmega328 based design.
    [adapter-B_Cu.gbl, adapter-B_Mask.gbs, adapter-B_SilkS.gbo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]
2013-08-21 Fixed errors in four panel 32mm matrix driver.
    [driver.dsn, driver.kicad_pcb, driver.sch]
2013-08-21 Finished initial verision of four matrix atmega328 based design.
    [comm.dsn, comm.kicad_pcb, driver.dsn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]
2013-08-22 Finished initial version of four matrix atmega328 based design.
    [driver.dsn, driver.kicad_pcb, driver.sch]
2013-08-22 Modified atmega328 comm pcb - moved traces out from under osc.
    [comm.kicad_pcb]
2013-08-22 Added missing library to 1-matrix atmega328 based design.
    [flypanels.sch]
2013-08-26 Modified 4 matrix atmega328 design. Added pin change interrupts and re-routed.
    [comm.dsn, comm.kicad_pcb, comm.sch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]
2013-08-26 Created gerber files and BOM for 4-matrix atmega328 and max6960 PCBs.
    [BOM.xls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]
2013-09-23 Added programmer pcb for atmega328 four panel 20mm matrix design.
    [programmer.dsn, programmer.kicad_pcb, programmer.sch]
2013-09-24 Added programming/development (top) for the 4x20mm atmega328 panel design.
    [programmer.dsn, programmer.kicad_pcb, programmer.sch]
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2013-09-24 Added bottom pcb for 4x20mm atmega328 panel driver.
    [programmer.dsn, programmer.kicad_pcb, programmer.sch]
2013-09-24 Added annotations to 4x20mm atmega328 driver programmer top pcb.
    [programmer.kicad_pcb]
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2013-10-04 Fixed minor issues with test arenas and programmer pcbs.
    [arena.kicad_pcb, programmer.sch]
2013-11-02 Added second communications header w/ common CS lines to atmega328 4x20mm test arena.
    [arena.sch]
2013-11-02 Added common CS SPI header to 4x20mm max6960 test arena. Fixed minor issue with 4x20mm atmega328 test arena.
    [arena.sch]
2013-11-09 Added 3rd spi header to test arenas. Third header has 6 spi buses w/ 5 common cs lines.
    [arena.dsn, arena.kicad_pcb, arena.sch]
2013-11-13 Created gerber files for test_arena and programmer pcbs. Fixed of few small errors.
    [arena-B_Cu.gbl, arena-B_Mask.gbs, arena-B_SilkS.gbo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]
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2013-12-28 Finished BOMs for atmeg328 and max6960 20mm four panel test arenas and programmers.
    [BOM.xls]
2014-01-29 Slightly modified the programmer and test arena BOMs - added 2nd version of 15ps female reseptical as the original doesn't seem to be available.
    [BOM.xls]
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2014-07-17 Added new driver programmer for 4x20mm atmega328 driver. Fixed issue with resistors and LED matrices on driver, then re-routed the board.
    [BOM.xls, driver.dsn, driver.kicad_pcb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]
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2014-08-05 Fixed error in v0.2 of atmega328 4x20mm driver programmer.
    [programmer.dsn, programmer.kicad_pcb]
2014-08-05 Modified version # text on PCB and created new set of gerber files.
    [programmer-B_Cu.gbl, programmer-B_Mask.gbs, programmer-B_SilkS.gbo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]
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2014-09-11 Fixed error on 4-th driver in atmega328 4x20mm subpanel. Rerouted (preliminary). Still need to remake gerbers, update revision number, etc.
    [BOM.xls, driver.dsn, driver.kicad_pcb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]
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2014-10-08 Worked on v0.2 test arena for atmega328 4x20mm panels. Added mosfet switch for reset. Modified for chaining via the 20x2 header so that we can drive 12 columns of panels.
    [arena.dsn, arena.kicad_pcb, arena.sch]
2014-10-08 Modified pwr,gnd and reset_pan trace widths. Re-routed.
    [arena.dsn, arena.kicad_pcb, arena.sch]
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2014-10-27 Added note about error in reset MOSFET circuit on test arena.
    [arena.sch]
2015-04-01 Added version 0.3 of comm pcb. Still need to create gerber files.
    [BOM.xls, comm.dsn, comm.kicad_pcb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]
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2015-04-09 Re-routed driver so that there are no traces going through the clocks.
    [driver-B_Cu.gbl, driver-B_Mask.gbs, driver-B_SilkS.gbo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]
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2015-04-20 Fixed silkscreen issue on driver.
    [driver-B_Cu.gbl, driver-B_Mask.gbs, driver-B_SilkS.gbo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]
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2015-08-18 Fixed issues with both comm and driver programmers - power orientation on dc jack.
    [BOM.xls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]
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2015-10-05 Fixed issue in 12-18 arena BOM.
    [BOM.xls]
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2016-02-02 Added version of drill files for OSH park manufacturing - different drill file format.
    [flypanels-B_Mask.gbs, flypanels-B_SilkS.gbo, flypanels-Back.gbl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]
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2016-04-30 Added new design for ver3 driver 4x20mm matrix (sized) with leds built in.
    [BOM.xls, driver.dsn, driver.kicad_pcb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]
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2016-05-10 Added footprint for 2x2 SMD header. Did preliminary fit test - OK but might step resistors and capacitors down to 0402 to make routing easier.
    [driver.kicad_pcb]
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2016-05-22 Added ver4 subdirectory for 4 matrix 20mm designs. Added driver design with complementary pair mosfets.
    [BOM.xls, driver.dsn, driver.kicad_pcb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]
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2016-05-23 Finished initial layout and routing of atmega328 G4 4x20mm matrix driver sub-panel with mosfet.
    [driver.dsn, driver.kicad_pcb]
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2016-08-03 Added note about error to atmega328 design.
    [flypanels.sch]
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2016-12-06 Worked on atmega328 4x20mm ver4. Modified silkscreen. Modified BOM changes 1% 82 Ohm resistor to 0.1% 160 Ohm resistor.
    [BOM.xls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]
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2016-12-27 Added xy position files. Fixed incorrect quantity in BOM.
    [BOM.xls]
2017-01-03 Added missing components to 4x20 atmega328 driver v0.4 r2 position file.
    [driver.kicad_pcb]
2017-01-09 Added missing footprints to atmega328 one panel 32mm v3 r2.
    [flypanels.kicad_pcb]
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2023-05-30 Remade gerbers. Fixed issues with CPL file so parts are oriented correctly.
    [BOM_JLCPCB_comm_v0p5_rev1.xlsx, BOM_master_comm_v0p5_rev.xlsx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]
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
